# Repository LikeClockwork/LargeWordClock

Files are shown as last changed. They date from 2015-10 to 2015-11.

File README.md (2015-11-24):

# Like Clockwork Large Word Clock Design Files and Software

This repository holds the PCB/laser etch design files and Arduino code for my version of the word clock.

These PCBs and the laser cut glass faces are currently available via my store at: http://www.likeclockworkdesign.com/collections/kits/products/the-standard-makers-kit

The PCB measures 399x399mm and the glass faceplace measures 17"x17".

The PCBs are Arduino compatible and it runs the “Arduino on a breadboard” bootloader. The microcontroller is a Atmega328p (TQFP package) running at 8MHz that drives four 16x8 LED (512 LEDs) matrixes via four HT16K33’s. Time keeping is accomplished using a DS321 real time clock.  There is a linear power regulator on board to step down 9-12V input voltage to 5V. 

All unused Arduino pins are broken out to a pin header. Happy hacking!

The posted PCBs have been fabricated, assembled, and confirmed as working with the posted code.

*Upcoming Changes:*

The boards shipped ~~for the Kickstarter~~ going forward will have the following enhancements:
+ Addition of a footprint so that you can plug in standard Arduino shields. Done!

+ The ability to replace all ICs with prebuilt modules (Arduino Nano vs. Atmega328p, Adafruit matrix drivers vs. HT16K33s) for those who don’t want to drag solder tiny leads. Done!

+ Addition of a prototyping area to make use of all that extra real-estate. Done!

+ Addition of an Open Source Hardware logo. Done!

*Thanks to:*

+ The Kickstarter Backers
+ CERN for building KiCad and making it free.
+ Adafruit for their great libraries and making awesome breakout boards.

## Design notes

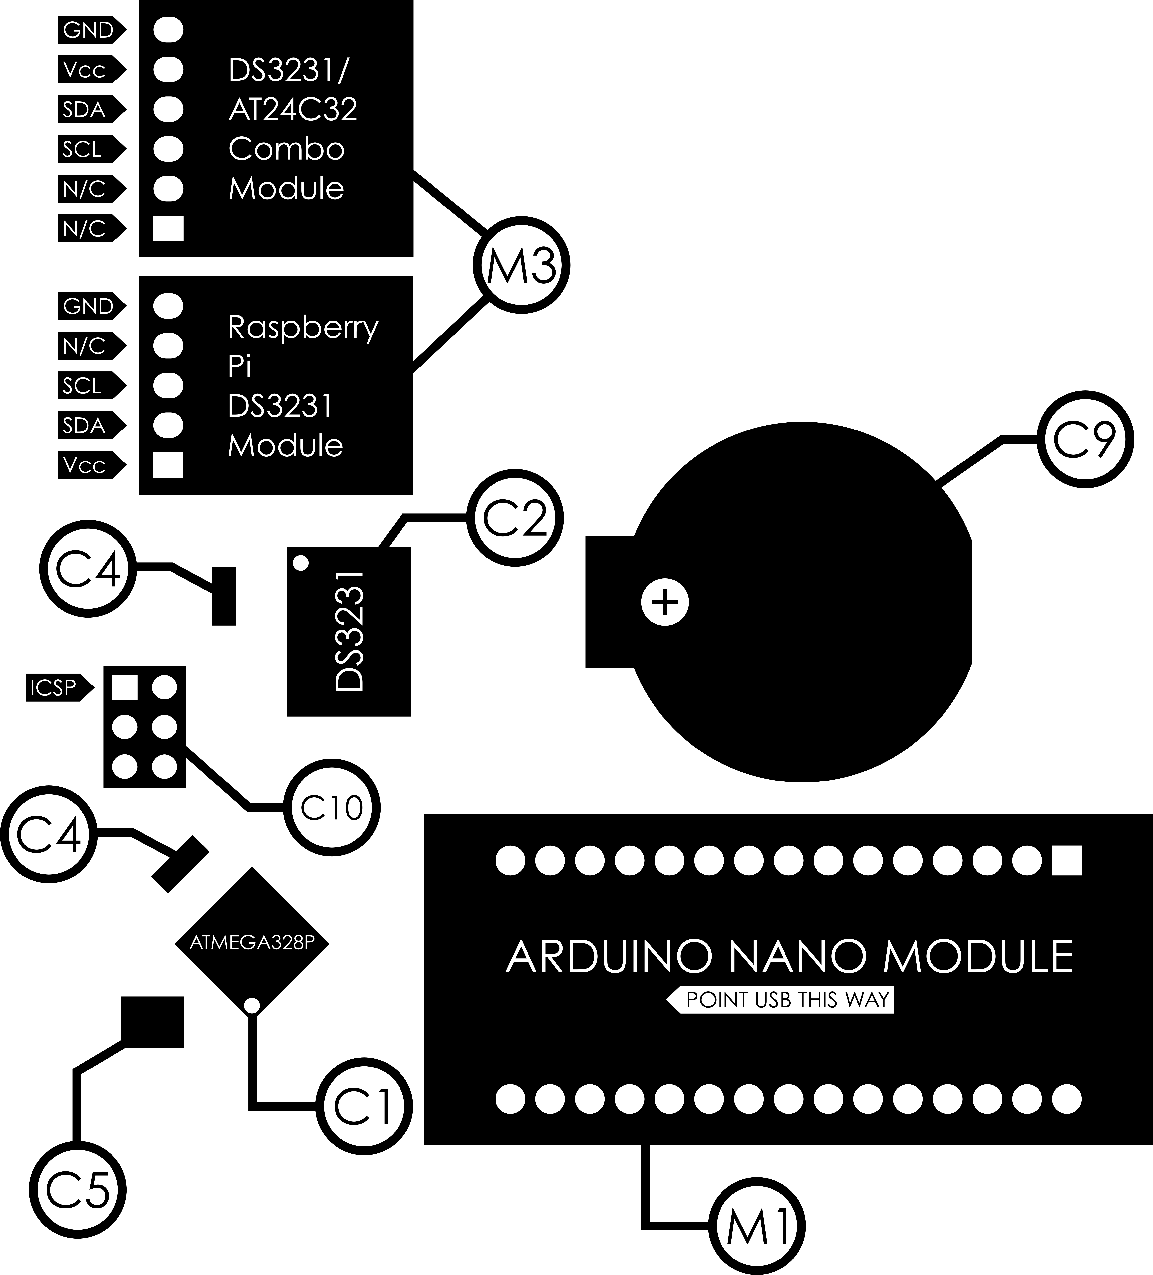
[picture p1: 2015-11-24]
KiCad/LargeKickstarter/SVG/nano_section.png

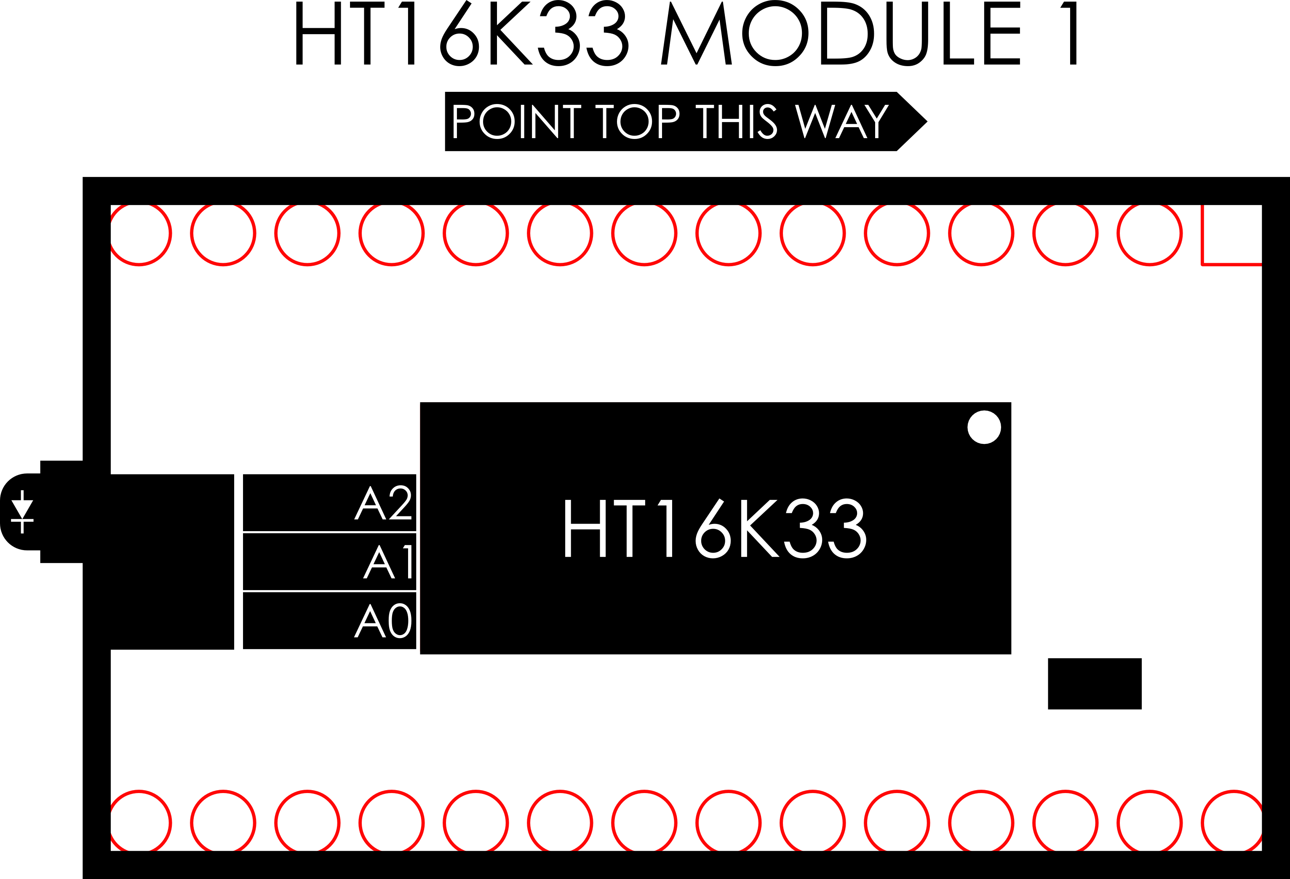
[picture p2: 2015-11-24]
KiCad/LargeKickstarter/SVG/HT-Module1.png

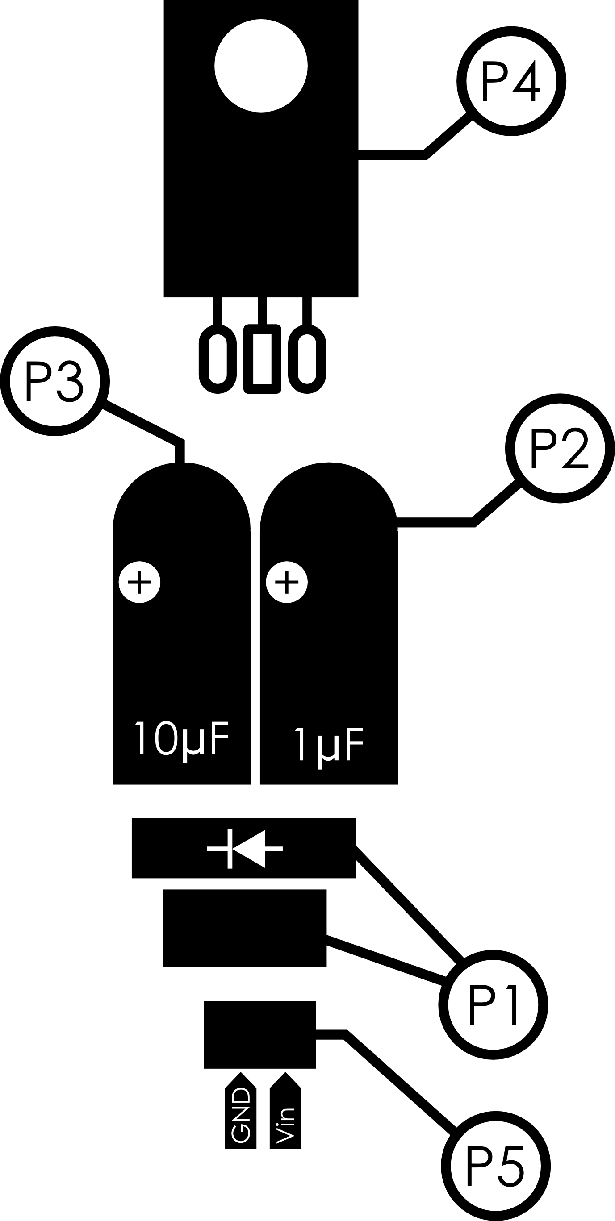
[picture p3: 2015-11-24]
KiCad/LargeKickstarter/SVG/power_section.png

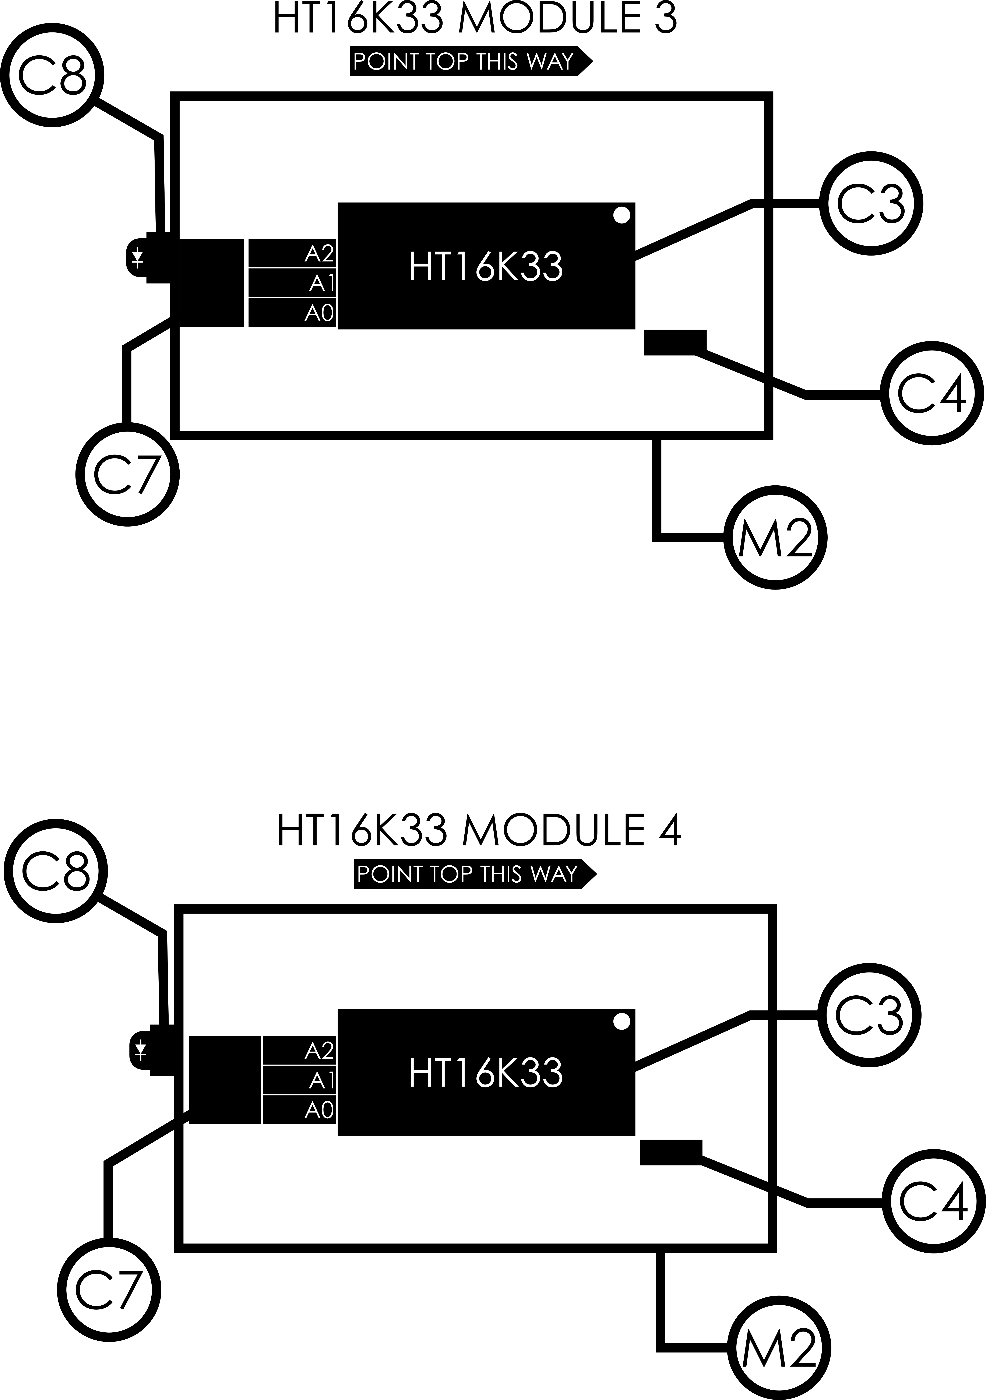
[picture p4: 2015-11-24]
KiCad/LargeKickstarter/SVG/bottom_matrix.png

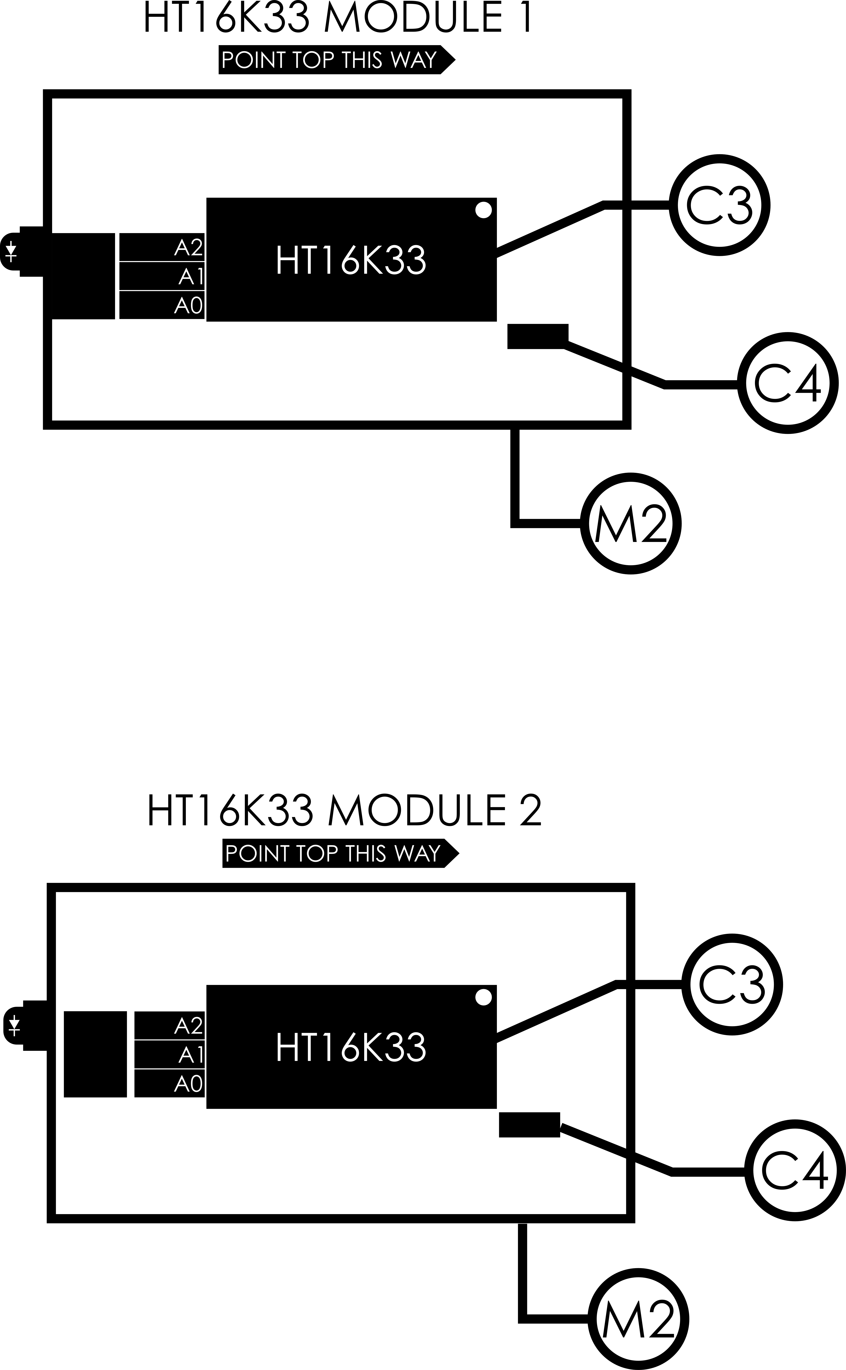
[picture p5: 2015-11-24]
KiCad/LargeKickstarter/SVG/top_matrix.png

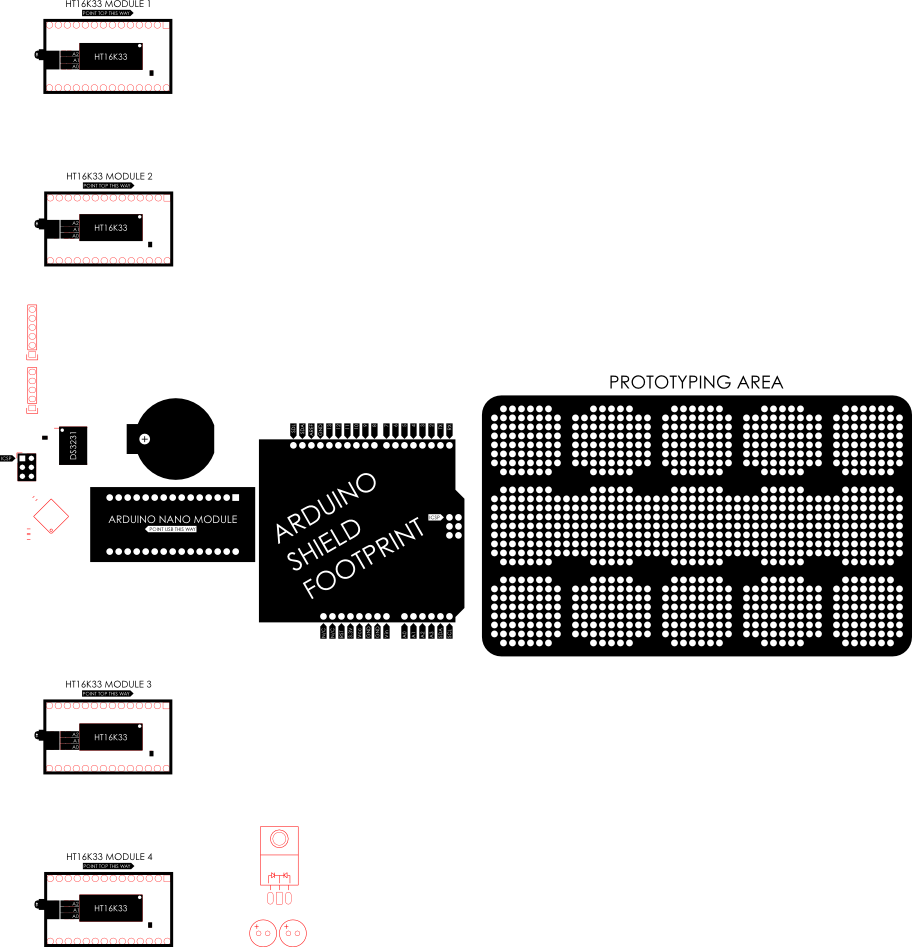
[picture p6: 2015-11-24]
KiCad/LargeKickstarter/SVG/g44480-2.png

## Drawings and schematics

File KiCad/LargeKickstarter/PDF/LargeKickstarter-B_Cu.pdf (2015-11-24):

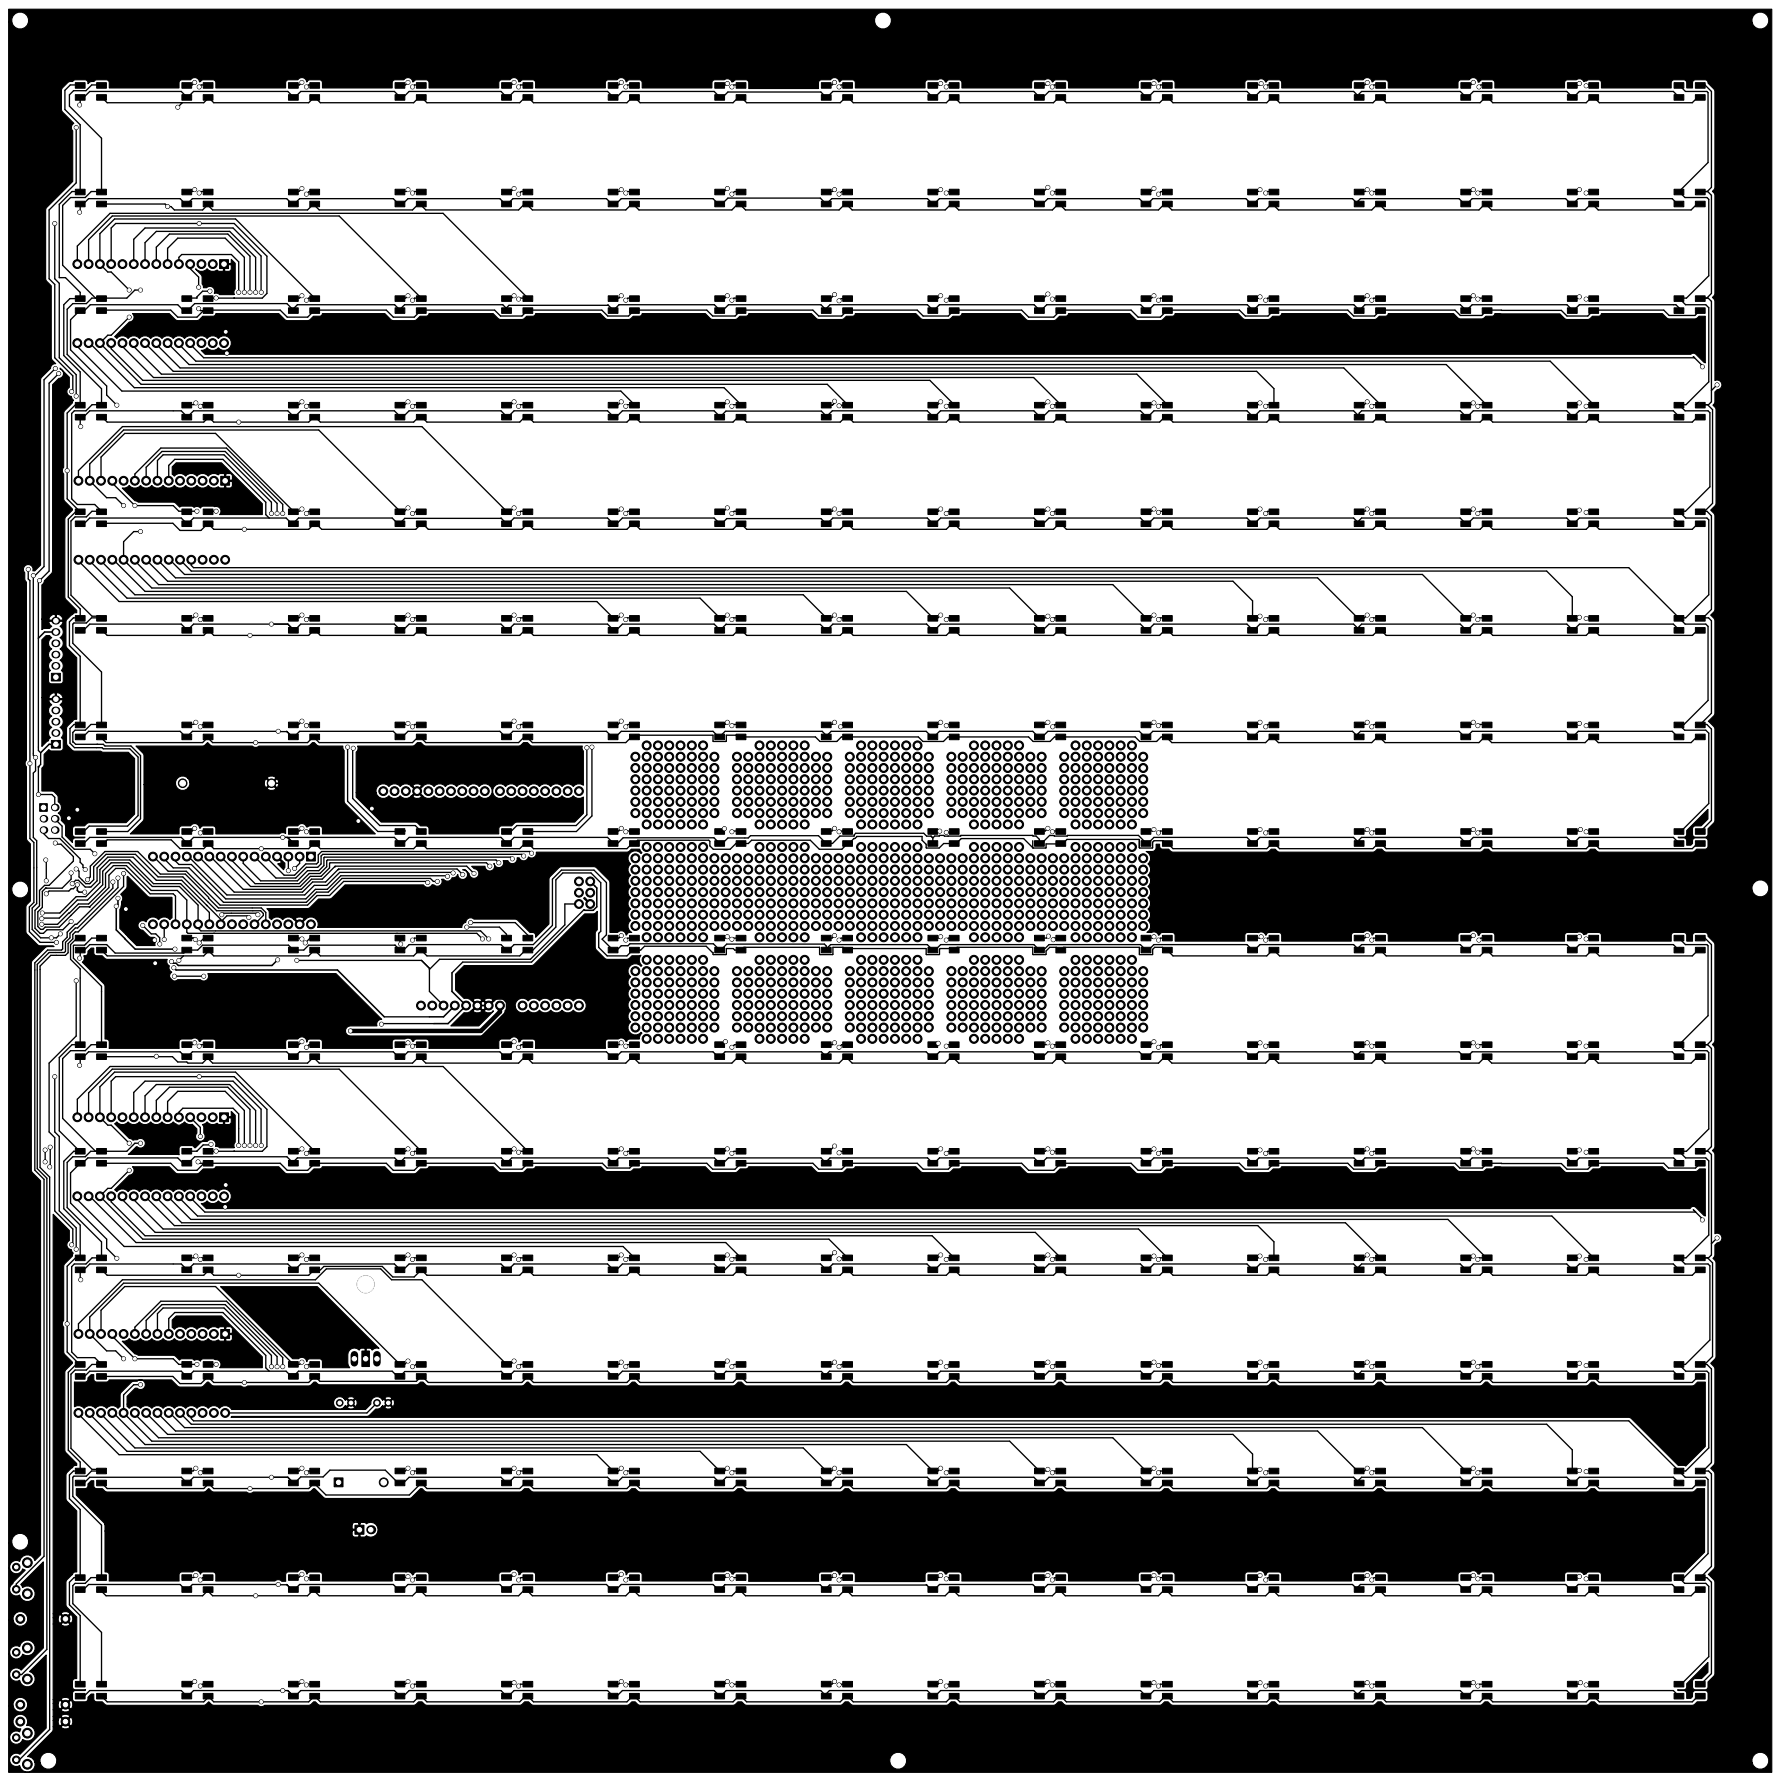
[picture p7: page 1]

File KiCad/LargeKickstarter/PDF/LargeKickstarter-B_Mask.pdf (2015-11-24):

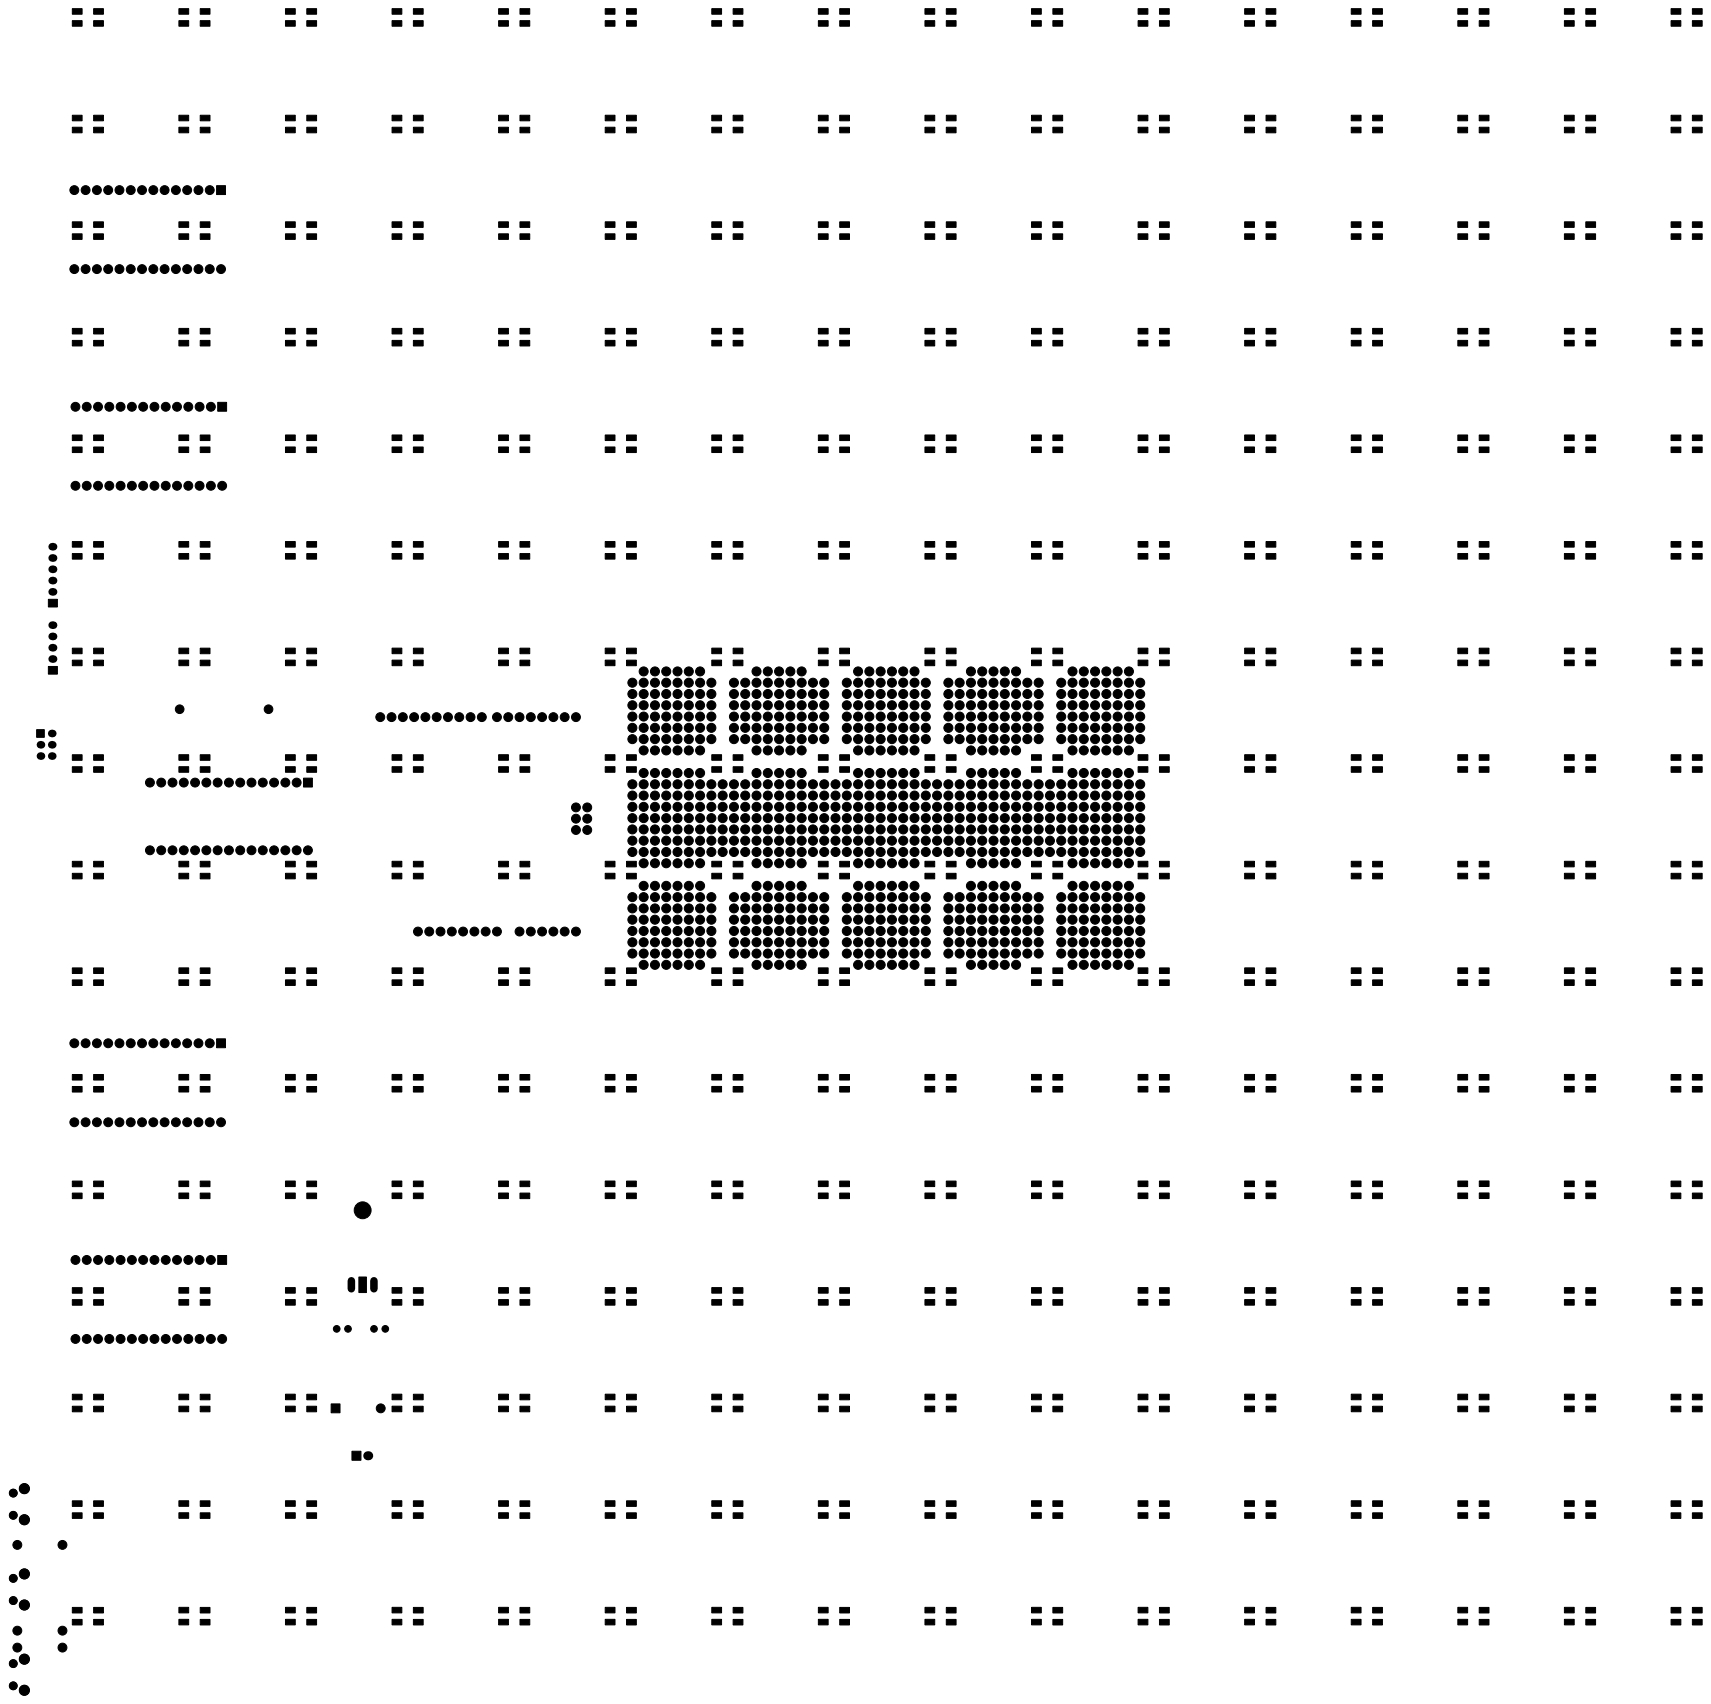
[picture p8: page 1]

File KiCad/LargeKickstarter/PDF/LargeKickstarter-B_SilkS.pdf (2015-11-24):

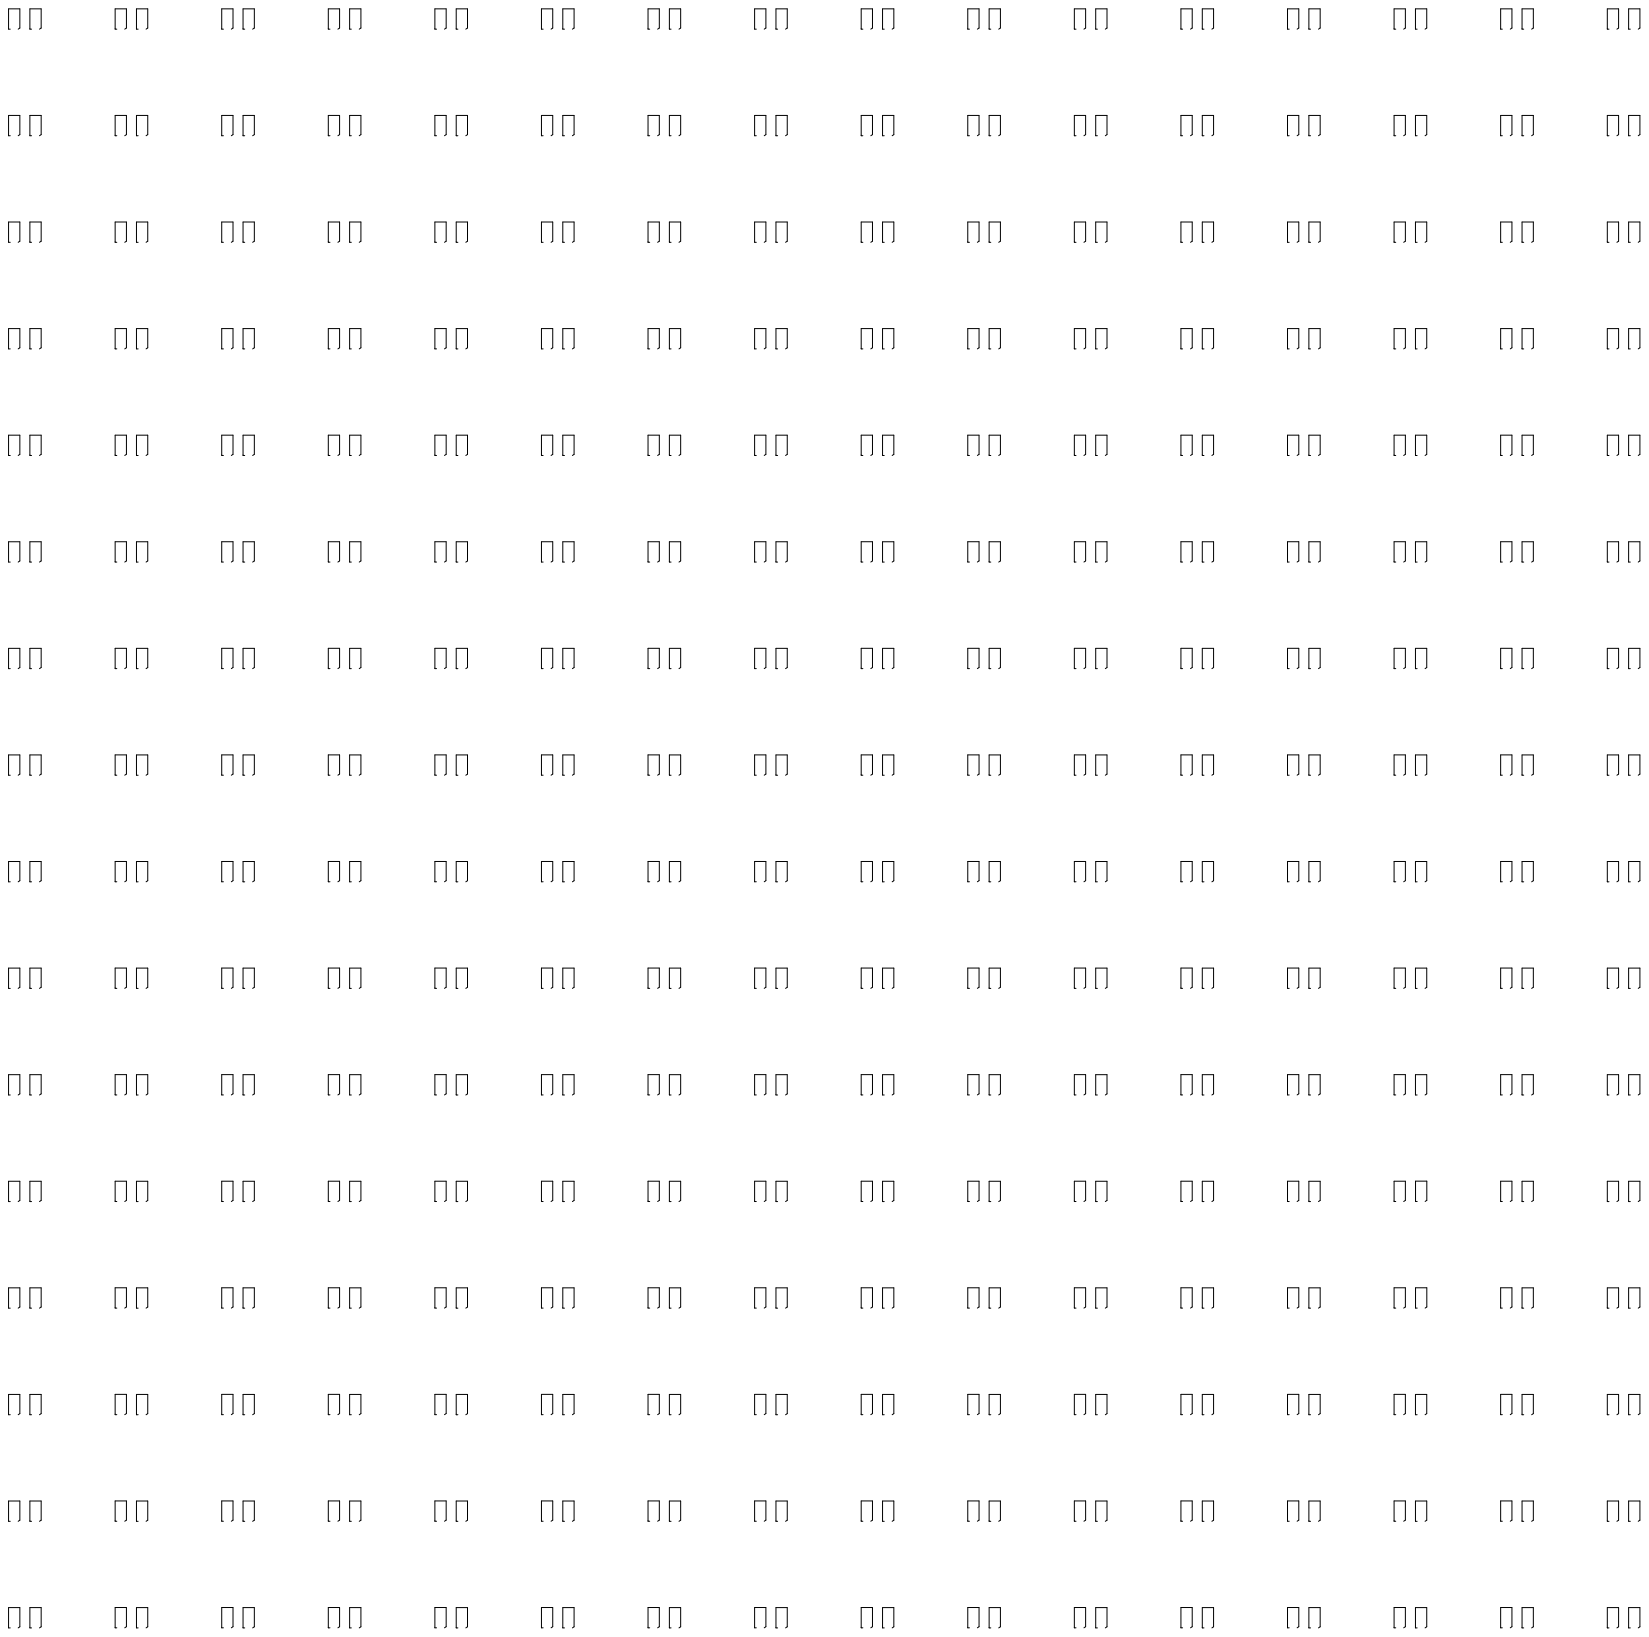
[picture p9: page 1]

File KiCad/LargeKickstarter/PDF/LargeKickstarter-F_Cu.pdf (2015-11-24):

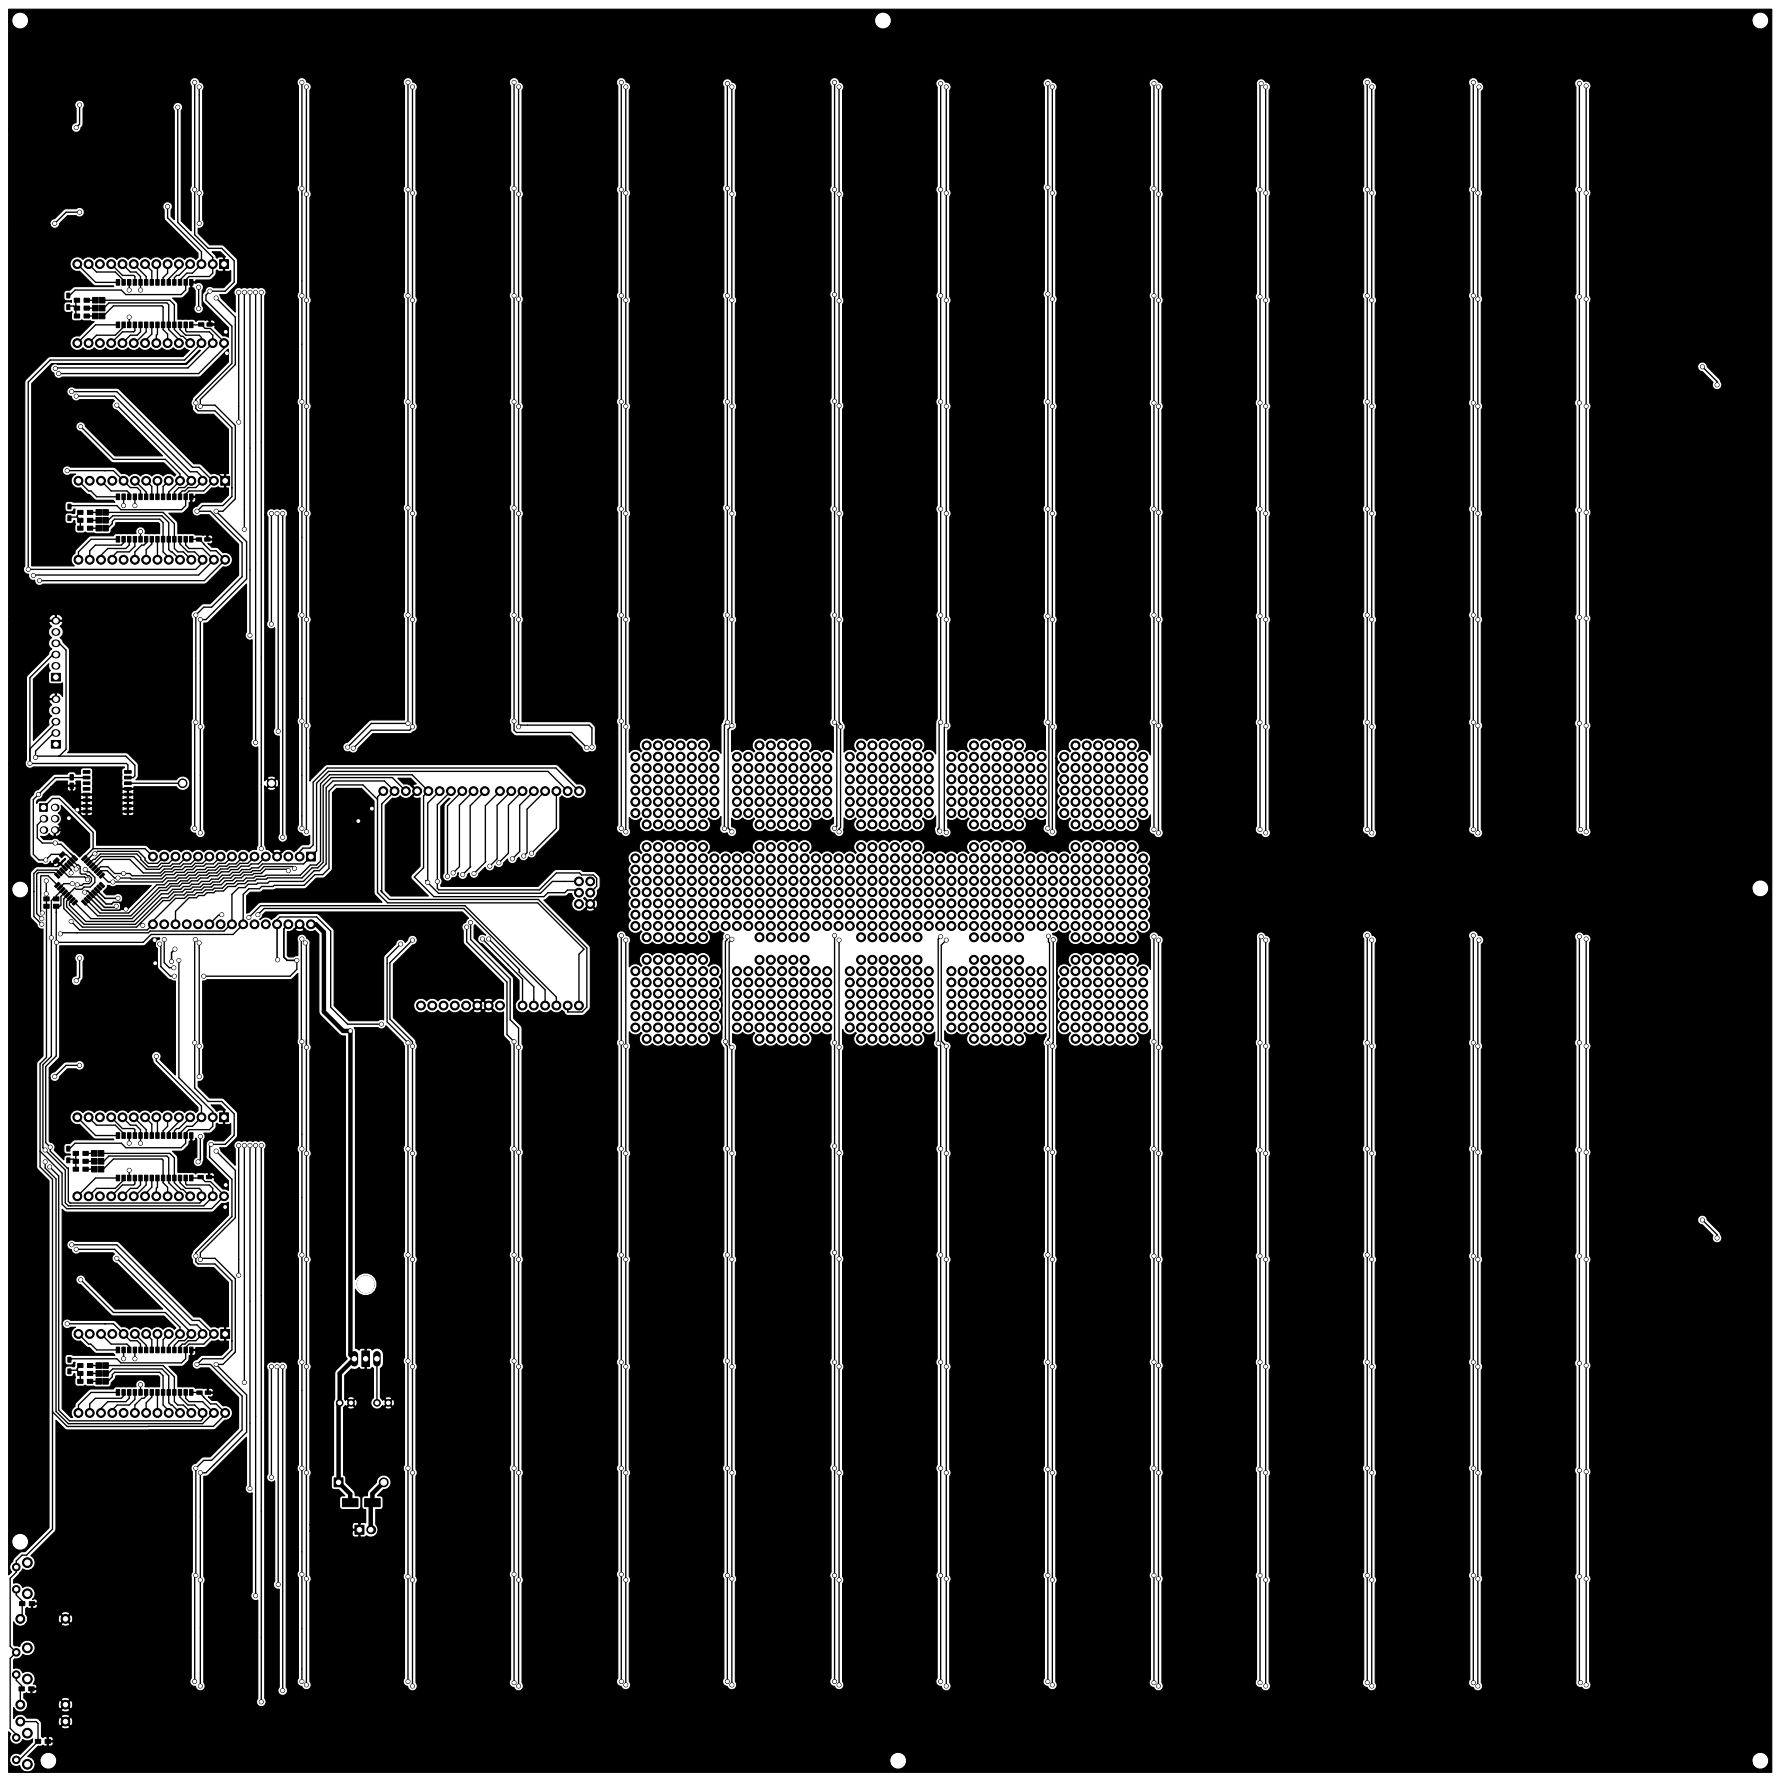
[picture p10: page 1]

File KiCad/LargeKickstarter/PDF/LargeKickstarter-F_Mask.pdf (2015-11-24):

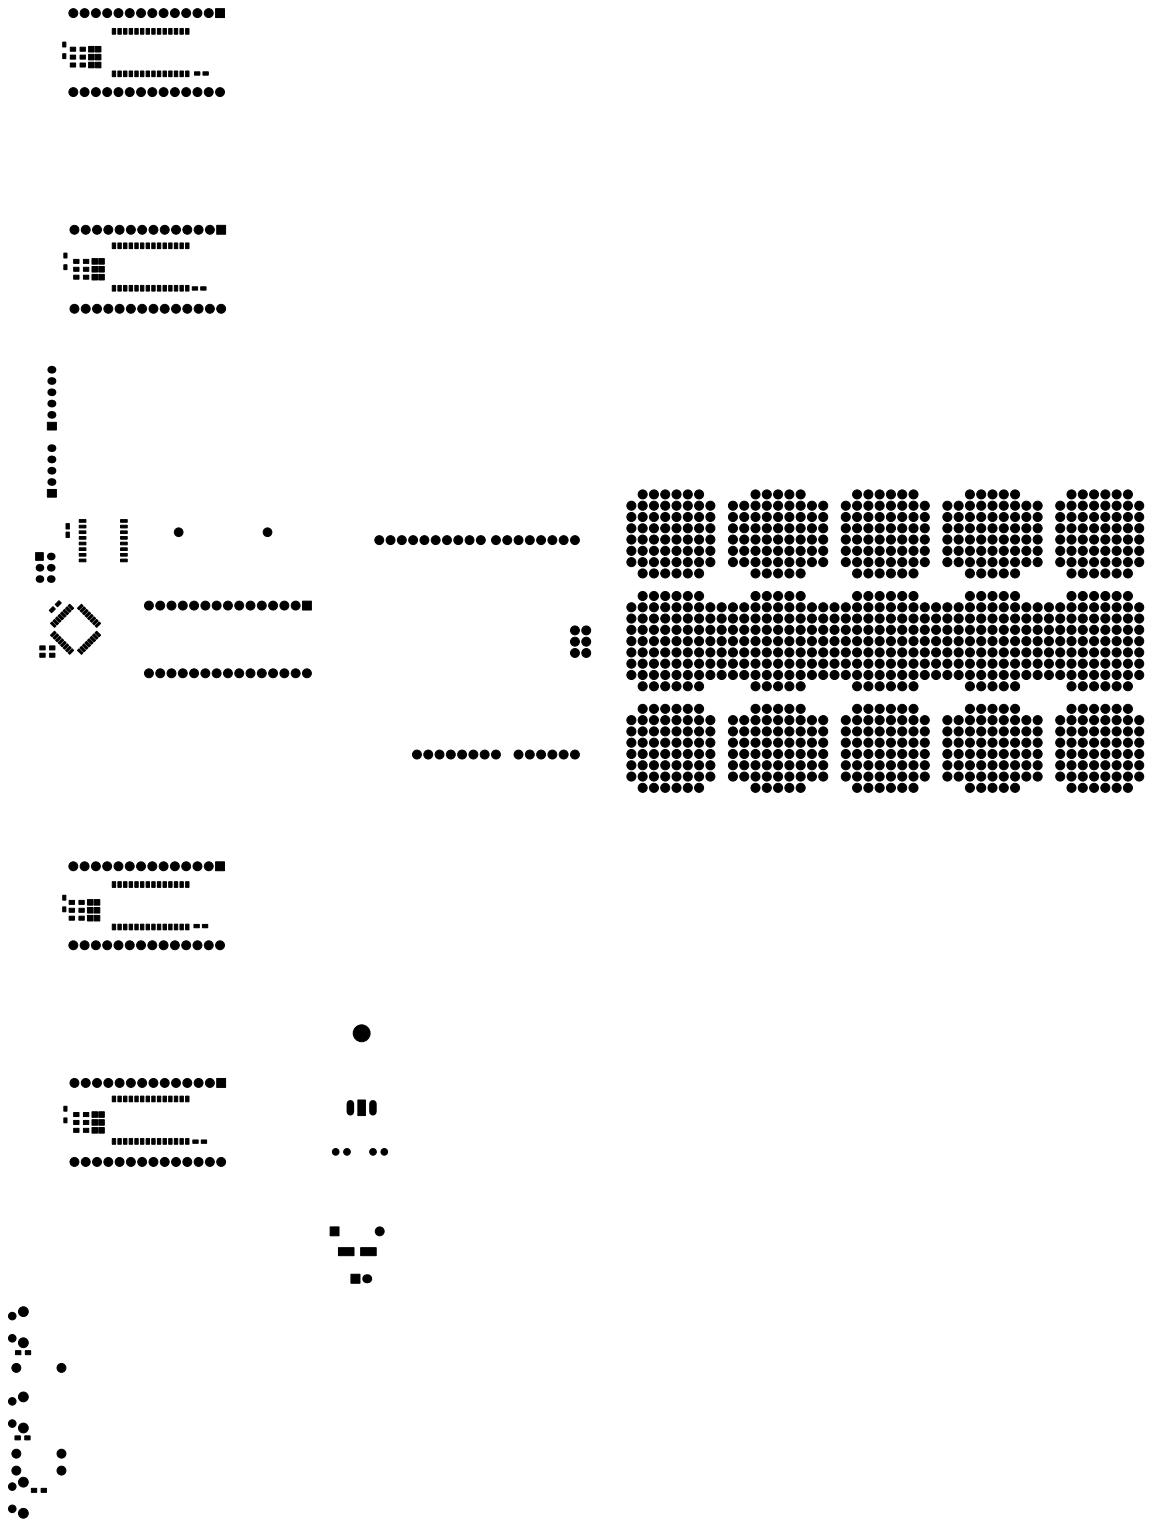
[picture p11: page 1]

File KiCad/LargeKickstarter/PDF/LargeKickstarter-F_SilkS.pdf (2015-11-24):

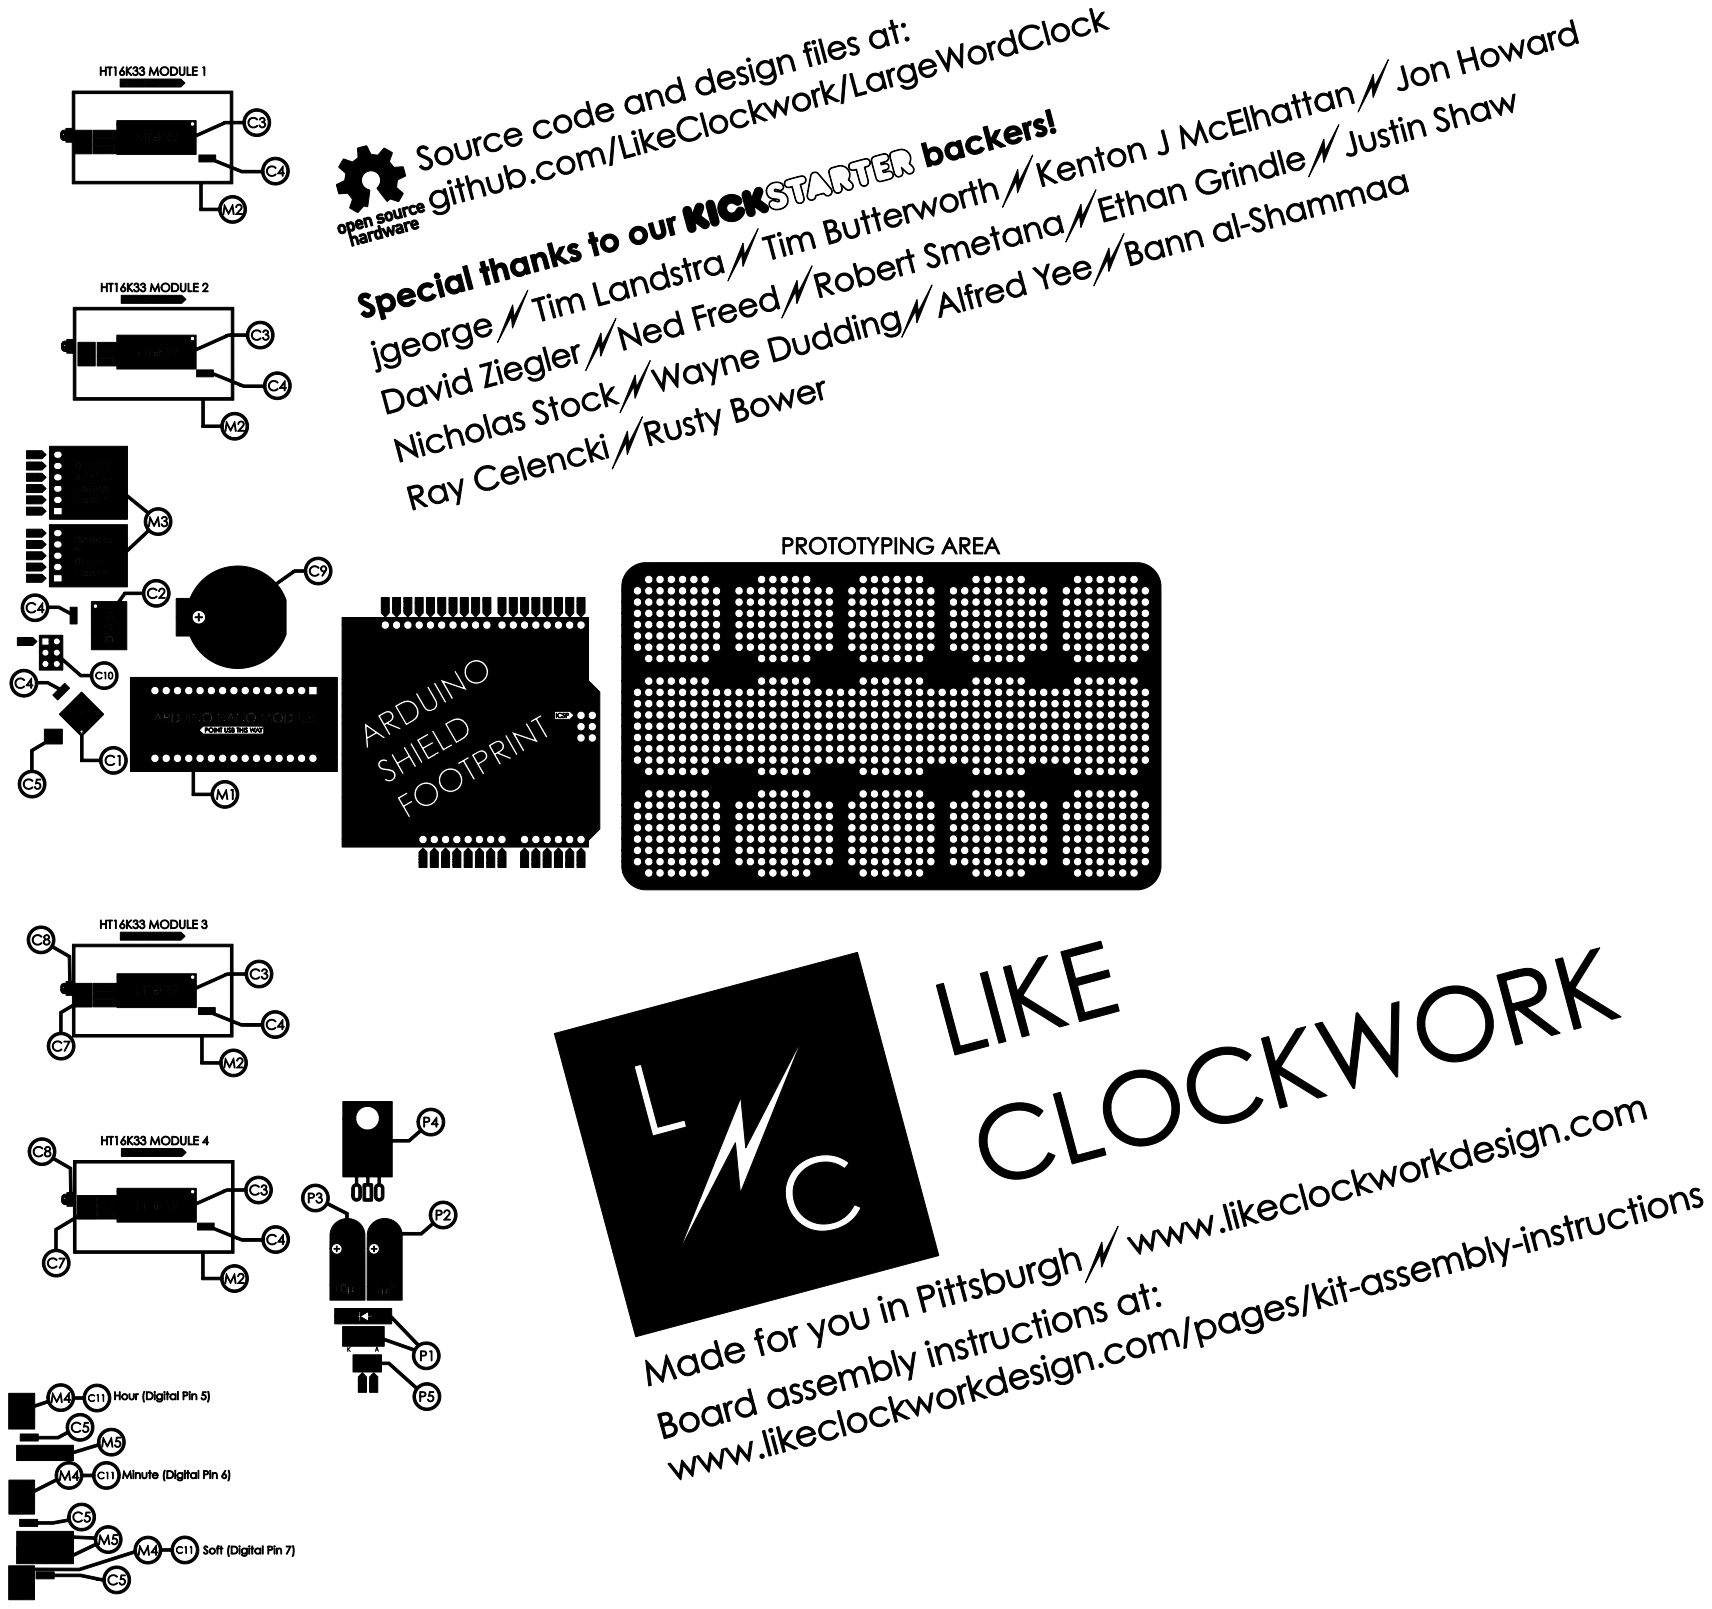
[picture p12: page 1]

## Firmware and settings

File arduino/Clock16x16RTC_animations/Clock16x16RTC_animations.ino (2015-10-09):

#include <Wire.h>
#include <RTClib.h>
#include "Adafruit_LEDBackpack.h"
#include "Adafruit_GFX.h"
#include "Clock16x16mapping.h"


RTC_DS1307 RTC;
Adafruit_8x16matrix matrix = Adafruit_8x16matrix();
Adafruit_8x16matrix matrix2 = Adafruit_8x16matrix();


uint16_t active[16];  //Holds active matrix
uint16_t last[16];  //Holds previous matrix

unsigned int curHours;
unsigned int hours = 99;
unsigned int curMins;
unsigned int mins = 99;
int aniChoice = 0;

void setup() { 
  //Serial.begin(57600);

  
  RTC.begin();
  delay(100);
 
matrix.begin(0x71);  // pass in the address
matrix2.begin(0x70);  // pass in the address
delay(100);
 
 matrix.clear();
 matrix2.clear();
 matrix.writeDisplay();
 matrix2.writeDisplay();
 matrix2.drawPixel(8, 15, LED_ON);
 matrix2.writeDisplay();  
 matrix2.drawPixel(8, 15, LED_OFF);
 matrix2.writeDisplay();  
 matrix2.drawPixel(8, 15, LED_ON);
 matrix2.writeDisplay();  
 matrix2.drawPixel(8, 15, LED_OFF);
 matrix2.writeDisplay(); 

 pinMode(5, INPUT);
 pinMode(6, INPUT);
 pinMode(7, INPUT);

  if(!RTC.isrunning()) {
    RTC.adjust(DateTime(2015,4,18,0,0,0));
  }

  DateTime now = RTC.now();

  hours = now.hour();
  mins = now.minute(); 
  doAnimation();  
  delay(100);

}

unsigned long currentMillis = millis();
unsigned long previousMillis = 0; 
unsigned long resetMillis = 0; 
unsigned long pressCheckA0 = 0;
unsigned long pressCheckA1 = 0;
unsigned long pressCheckA2 = 0;


bool A0pressed = false;
bool A1pressed = false;
bool A2pressed = false;
bool A0read = false;
bool A1read = false;
bool A2read = false;

void loop () {
  
 
   if((unsigned long)(currentMillis - previousMillis) >= 5000)  {
   
    //Serial.print(hours);
    //Serial.print(':');
    //Serial.println(mins);
    checkTime();
    previousMillis = currentMillis; 
     
  }
   
  
  if( digitalRead(5) == HIGH && A0pressed == false) {
     A0pressed = true;
     pressCheckA0 = currentMillis;
     A0read = false;
  }  

  if( digitalRead(6) == HIGH && A1pressed == false) {
      A1pressed = true;
      pressCheckA1 = currentMillis;
      A1read = false;
  }  


  if( digitalRead(7) == HIGH && A2pressed == false) {
      A2pressed = true;
      pressCheckA2 = currentMillis;
      A2read = false;
  }

  if( A0pressed == true && A0read == false && (unsigned long)(currentMillis - pressCheckA0) >= 50) {
      DateTime now = RTC.now();
      int newHour = now.hour() + 1;
      if (newHour > 23) {
         newHour = 0; 
      }
      RTC.adjust(DateTime(now.year(),now.month(),now.day(),newHour,now.minute(),now.second()));
      hours = newHour;
      mins = now.minute(); 
      curHours = newHour;
      curMins = now.minute(); 
      wipe();
      assemble();
      drawDisplay();
      A0read = true;
  }
  
  if( A1pressed == true && A1read == false && (unsigned long)(currentMillis - pressCheckA1) >= 50) {
      DateTime now = RTC.now();   
      int newMinute = now.minute() + 1;
      if (newMinute > 59) {
         newMinute = 0; 
      }
      RTC.adjust(DateTime(now.year(),now.month(),now.day(),now.hour(),newMinute,now.second()));
      hours = now.hour();
      mins = newMinute; 
      curHours = now.hour();
      curMins = newMinute;
      wipe();
      assemble();
      drawDisplay();
      A1read = true;
  }


  if( A2pressed == true && A2read == false && (unsigned long)(currentMillis - pressCheckA2) >= 50) {  
      aniChoice++;
      sampleAnimation();
      A2read = true;
  }


  if( digitalRead(5) == LOW) {
     A0pressed = false; 
     A0read = false;
  }
   
  if( digitalRead(6) == LOW) {
     A1pressed = false; 
     A1read = false;
  } 
 
  if( digitalRead(7) == LOW) {
     A2pressed = false; 
     A2read = false;
  } 

  wipe();
  assemble();
  delay(10); 
  currentMillis = millis();
}

void checkTime () {
  DateTime now = RTC.now();
  curHours = now.hour();
  curMins = now.minute();  

  if (curHours != hours || curMins != mins) {
    hours = curHours;
    mins = curMins;
   //software_Reset();
    doAnimation();

  }  
  
}



void assemble() {
  
  for( int i = 0; i < 16; i++ ) {
    active[i] = active[i] | pgm_read_word(&(it_is[i]));
  }  
  
  
  //flag midnight   
  if (hours == 0 && mins == 0 ) {
    for( int i = 0; i < 16; i++ ) {
      active[i] = active[i] | pgm_read_word(&(midnight[i]));
    }     
  }
  
  //flag noon   
  if ( hours == 12 && mins == 0) {
    for( int i = 0; i < 16; i++ ) {
      active[i] = active[i] | pgm_read_word(&(noon[i]));
    }     
  }
  
  //If it's between 12:01 and 5:59 in the PM, flag in the afternoon   
  if (hours > 12 && hours < 18 || ( hours == 12 && mins > 0 )) {
      for( int i = 0; i < 16; i++ ) {
        active[i] = active[i] | pgm_read_word(&(in_the_afternoon[i]));
      }
  }  
  
  //If it's between 6 and 8:59 in the PM, flag in the evening   
  if (hours > 17 && hours < 21) {
    for( int i = 0; i < 16; i++ ) {
      active[i] = active[i] | pgm_read_word(&(in_the_evening[i]));
    }     
  }
  
  
  //If it's between 9 and midnight in the PM, flag at night   
  if (hours > 20 ) {
    for( int i = 0; i < 16; i++ ) {
      active[i] = active[i] | pgm_read_word(&(at_night[i]));
    }     
  }
  
  //If it's between 12:01 and 11:59 in the AM, flag in the morning  
  if ((hours > 0 && hours < 12) || (hours == 0 && mins > 0) ) {
      for( int i = 0; i < 16; i++ ) {
        active[i] = active[i] | pgm_read_word(&(in_the_morning[i]));
      }   
  }

  if ( mins == 0  && (hours != 12 && hours != 0)) {
    for( int i = 0; i < 16; i++ ) {
      active[i] = active[i] | pgm_read_word(&(o_clock[i]));
    }
  }  
  
  if ( mins < 10 && mins > 0) {
    for( int i = 0; i < 16; i++ ) {
      active[i] = active[i] | pgm_read_word(&(o[i]));
    }
  }  
  
  if ( hours == 12 && mins != 0) {
    for( int i = 0; i < 16; i++ ) {
      active[i] = active[i] | pgm_read_word(&(h12[i]));
    }
  }  
  
  if ( hours == 0 && mins != 0) {
    for( int i = 0; i < 16; i++ ) {
      active[i] = active[i] | pgm_read_word(&(h12[i]));
    }
  }  
  
  if ( hours == 1 || hours == 13) {
    for( int i = 0; i < 16; i++ ) {
      active[i] = active[i] | pgm_read_word(&(h1[i]));
    }
  }
  
  if ( hours == 2 || hours == 14) {
    for( int i = 0; i < 16; i++ ) {
      active[i] = active[i] | pgm_read_word(&(h2[i]));
    }
  }
  
  if ( hours == 3 || hours == 15) {
    for( int i = 0; i < 16; i++ ) {
      active[i] = active[i] | pgm_read_word(&(h3[i]));
    }
  } 
  
  if ( hours == 4 || hours == 16) {
    for( int i = 0; i < 16; i++ ) {
      active[i] = active[i] | pgm_read_word(&(h4[i]));
    }
  } 
  
  if ( hours == 1) {
    for( int i = 0; i < 16; i++ ) {
      active[i] = active[i] | pgm_read_word(&(h1[i]));
    }
  } 
  
  if ( hours == 5 || hours == 17) {
    for( int i = 0; i < 16; i++ ) {
      active[i] = active[i] | pgm_read_word(&(h5[i]));
    }
  } 
  
  if ( hours == 6 || hours == 18) {
    for( int i = 0; i < 16; i++ ) {
      active[i] = active[i] | pgm_read_word(&(h6[i]));
    }
  } 
  
  if ( hours == 7 || hours == 19) {
    for( int i = 0; i < 16; i++ ) {
      active[i] = active[i] | pgm_read_word(&(h7[i]));
    }
  } 
  
  if ( hours == 8 || hours == 20) {
    for( int i = 0; i < 16; i++ ) {
      active[i] = active[i] | pgm_read_word(&(h8[i]));
    }
  } 
  
  if ( hours == 9 || hours == 21) {
    for( int i = 0; i < 16; i++ ) {
      active[i] = active[i] | pgm_read_word(&(h9[i]));
    }
  } 
  
  if ( hours == 10 || hours == 22) {
    for( int i = 0; i < 16; i++ ) {
      active[i] = active[i] | pgm_read_word(&(h10[i]));
    }
  }
  
  if ( hours == 11 || hours == 23) {
    for( int i = 0; i < 16; i++ ) {
      active[i] = active[i] | pgm_read_word(&(h11[i]));
    }
  } 

  
  if ( mins == 1 || mins == 21 || mins == 31 || mins == 41 || mins == 51) {
    for( int i = 0; i < 16; i++ ) {
      active[i] = active[i] | pgm_read_word(&(m1[i]));
    }
  } 
  
  if ( mins == 2 || mins == 22 || mins == 32 || mins == 42 || mins == 52) {
    for( int i = 0; i < 16; i++ ) {
      active[i] = active[i] | pgm_read_word(&(m2[i]));
    }
  }
  
  if ( mins == 3 || mins == 23 || mins == 33 || mins == 43 || mins == 53) {
    for( int i = 0; i < 16; i++ ) {
      active[i] = active[i] | pgm_read_word(&(m3[i]));
    }
  }
  
  if ( mins == 4 || mins == 24 || mins == 34 || mins == 44 || mins == 54) {
    for( int i = 0; i < 16; i++ ) {
      active[i] = active[i] | pgm_read_word(&(m4[i]));
    }
  }
  
  if ( mins == 5 || mins == 25 || mins == 35 || mins == 45 || mins == 55) {
    for( int i = 0; i < 16; i++ ) {
      active[i] = active[i] | pgm_read_word(&(m5[i]));
    }
  }
  
  if ( mins == 6 || mins == 26 || mins == 36 || mins == 46 || mins == 56) {
    for( int i = 0; i < 16; i++ ) {
      active[i] = active[i] | pgm_read_word(&(m6[i]));
    }
  }
  
  if ( mins == 7 || mins == 27 || mins == 37 || mins == 47 || mins == 57) {
    for( int i = 0; i < 16; i++ ) {
      active[i] = active[i] | pgm_read_word(&(m7[i]));
    }
  }
  
  if ( mins == 8 || mins == 28 || mins == 38 || mins == 48 || mins == 58) {
    for( int i = 0; i < 16; i++ ) {
      active[i] = active[i] | pgm_read_word(&(m8[i]));
    }
  }
  
  if ( mins == 9 || mins == 29 || mins == 39 || mins == 49 || mins == 59) {
    for( int i = 0; i < 16; i++ ) {
      active[i] = active[i] | pgm_read_word(&(m9[i]));
    }
  }
  
  if ( mins == 10 ) {
    for( int i = 0; i < 16; i++ ) {
      active[i] = active[i] | pgm_read_word(&(m10[i]));
    }
  }  
  
  if ( mins == 11 ) {
    for( int i = 0; i < 16; i++ ) {
      active[i] = active[i] | pgm_read_word(&(m11[i]));
    }
  }  
  
  if ( mins == 12 ) {
    for( int i = 0; i < 16; i++ ) {
      active[i] = active[i] | pgm_read_word(&(m12[i]));
    }
  }  
  
  if ( mins == 13 ) {
    for( int i = 0; i < 16; i++ ) {
      active[i] = active[i] | pgm_read_word(&(m13[i]));
    }
  }  
  
  if ( mins == 14 ) {
    for( int i = 0; i < 16; i++ ) {
      active[i] = active[i] | pgm_read_word(&(m14[i]));
    }
  }  
  
  if ( mins == 15 ) {
    for( int i = 0; i < 16; i++ ) {
      active[i] = active[i] | pgm_read_word(&(m15[i]));
    }
  }  
  
  if ( mins == 16 ) {
    for( int i = 0; i < 16; i++ ) {
      active[i] = active[i] | pgm_read_word(&(m16[i]));
    }
  }  
  
  if ( mins == 17 ) {
    for( int i = 0; i < 16; i++ ) {
      active[i] = active[i] | pgm_read_word(&(m17[i]));
    }
  }  
  
  if ( mins == 18 ) {
    for( int i = 0; i < 16; i++ ) {
      active[i] = active[i] | pgm_read_word(&(m18[i]));
    }
  }  
  
  if ( mins == 19 ) {
    for( int i = 0; i < 16; i++ ) {
      active[i] = active[i] | pgm_read_word(&(m19[i]));
    }
  }   
  
  if ( mins >= 20 && mins < 30 ) {
    for( int i = 0; i < 16; i++ ) {
      active[i] = active[i] | pgm_read_word(&(m20[i]));
    }
  }   
  
  if ( mins >= 30 && mins < 40 ) {
    for( int i = 0; i < 16; i++ ) {
      active[i] = active[i] | pgm_read_word(&(m30[i]));
    }
  }  
  
  if ( mins >= 40 && mins < 50 ) {
    for( int i = 0; i < 16; i++ ) {
      active[i] = active[i] | pgm_read_word(&(m40[i]));
    }
  }    
  
  if ( mins >= 50 && mins < 60 ) {
    for( int i = 0; i < 16; i++ ) {
      active[i] = active[i] | pgm_read_word(&(m50[i]));
    }
  } 

}

void wipe () {
    for( int i = 0; i < 16; i++ ) {
      active[i] = 0b0000000000000000;
    }  
}


//Animation functions

//No animation
void drawDisplay() {      
    
    matrix.clear();
    matrix2.clear();
    wipe();
    assemble();
    
     for( int y = 16; y >= 0; y-- ) {
       for( int x = 0; x < 16; x++) {  

         if(bitRead( active[15 - y] , 15 - x)) {
            if( y < 8) {
                matrix.drawPixel(y, x, LED_ON);  
            } else {
                matrix2.drawPixel(y - 8, x, LED_ON);                
            }
          } else {

          }
        } 
     }
      matrix.writeDisplay();  
      matrix2.writeDisplay(); 
}

//Fade out and back in
void fadeOut() {
     for(int b = 16; b >= 0; b--) {
       matrix.setBrightness(b); 
       matrix2.setBrightness(b); 
       delay(50);
    }
    wipe();
    assemble();
    drawDisplay();

    delay(100);

    for(int b = 0; b < 16 ; b++) {
       matrix.setBrightness(b); 
       matrix2.setBrightness(b); 
       delay(50);
    } 
}

//Random dissolve to all on, then fade back to time
void whiteOut () {
  
      int randomizer[256] = {
        1, 2, 3, 4, 5, 6, 7, 8, 9, 10, 11, 12, 13, 14, 15, 16,
        17, 18, 19, 20, 21, 22, 23, 24, 25, 26, 27, 28, 29, 30, 31, 32,
        33, 34, 35, 36, 37, 38, 39, 40, 41, 42, 43, 44, 45, 46, 47, 48,
        49, 50, 51, 52, 53, 54, 55, 56, 57, 58, 59, 60, 61, 62, 63, 64,
        65, 66, 67, 68, 69, 70, 71, 72, 73, 74, 75, 76, 77, 78, 79, 80,
        81, 82, 83, 84, 85, 86, 87, 88, 89, 90, 91, 92, 93, 94, 95, 96,
        97, 98, 99, 100, 101, 102, 103, 104, 105, 106, 107, 108, 109, 110, 111, 112,
        113, 114, 115, 116, 117, 118, 119, 120, 121, 122, 123, 124, 125, 126, 127, 128,
        129, 130, 131, 132, 133, 134, 135, 136, 137, 138, 139, 140, 141, 142, 143, 144,
        145, 146, 147, 148, 149, 150, 151, 152, 153, 154, 155, 156, 157, 158, 159, 160, 
        161, 162, 163, 164, 165, 166, 167, 168, 169, 170, 171, 172, 173, 174, 175, 176, 
        177, 178, 179, 180, 181, 182, 183, 184, 185, 186, 187, 188, 189, 190, 191, 192, 
        193, 194, 195, 196, 197, 198, 199, 200, 201, 202, 203, 204, 205, 206, 207, 208, 
        209, 210, 211, 212, 213, 214, 215, 216, 217, 218, 219, 220, 221, 222, 223, 224, 
        225, 226, 227, 228, 229, 230, 231, 232, 233, 234, 235, 236, 237, 238, 239, 240, 
        241, 242, 243, 244, 245, 246, 247, 248, 249, 250, 251, 252, 253, 254, 255, 256
      };  
  

     bubbleUnsort (randomizer, 256);    
  
     for( int i = 0; i < 256; i++) {
        
          int y = randomizer[i ]/16;
          int x = randomizer[i ]%16;
   
         if( y < 8) {
            matrix.drawPixel(y, x, LED_ON);  
          } else {
            matrix2.drawPixel(y - 8, x, LED_ON);                
          }

     
        matrix.writeDisplay();  
        matrix2.writeDisplay();
        
     }
     
     wipe();
     bubbleUnsort (randomizer, 256);    
     assemble();

     for( int i = 0; i < 256; i++) {
        
          int y = randomizer[i]/16;
          int x = randomizer[i]%16;
   
         if(bitRead( active[15 - y] , 15 - x)) {
            if( y < 8) {
                matrix.drawPixel(y, x, LED_ON);  
            } else {
                matrix2.drawPixel(y - 8, x, LED_ON);                
            }
          } else {
            if( y < 8) {
                matrix.drawPixel(y, x, LED_OFF);  
            } else {
                matrix2.drawPixel(y - 8, x, LED_OFF);                
            }            
          }
       
     
        matrix.writeDisplay();  
        matrix2.writeDisplay();
        
     }
}

//Horizontal sweep.
void sweep() {      
      
    for( int x = 0; x < 16; x++) {
      last[x] = active[x]; 
    }
    

     wipe();
     assemble();   
   
     for( int x = 0; x < 16; x++) {  
       
       for( int y = 16; y >= 0; y-- ) {   

         if(!bitRead( active[15 - y] , 15 - x)) {
            if( y < 8) {
                matrix.drawPixel(y, x, LED_OFF);  
            } else {
                matrix2.drawPixel(y - 8, x, LED_OFF);                
            }
          }
          matrix.writeDisplay();  
          matrix2.writeDisplay(); 
       }          
     }
     
     for( int x = 0; x < 16; x++) {  
       
       for( int y = 16; y >= 0; y-- ) {  
         
         if(bitRead( active[15 - y] , 15 - x)) {
            if( y < 8) {
                matrix.drawPixel(y, x, LED_ON);  
            } else {
                matrix2.drawPixel(y - 8, x, LED_ON);                
            }
          }
          
          matrix.writeDisplay();  
          matrix2.writeDisplay(); 
        } 
     }
}

//Matrixy.
void matrixy() {      
    wipe();
    assemble();
 
     int cols[16] = {0,1,2,3,4,5,6,7,8,9,10,11,12,13,14,15};
     bubbleUnsort( cols, 16);
 
     
     for(int r = 0; r < 2; r++) {
     
     for( int i = 0; i < 16; i++) {
     
     int x = cols[i];
     int x2 = cols[i+1];
     int x3 = cols[i+2];
     int x4 = cols[i+3];
 
     for( int y = 16; y >= 0; y-- ) {
                 
            if( y < 8) {
                matrix.drawPixel(y, x, LED_ON);
                matrix.drawPixel(y, x2, LED_ON);  
                matrix.drawPixel(y, x3, LED_ON);  
                matrix.drawPixel(y, x4, LED_ON);  
            } else {
                matrix2.drawPixel(y - 8, x, LED_ON);                
                matrix2.drawPixel(y - 8, x2, LED_ON);                
                matrix2.drawPixel(y - 8, x3, LED_ON);                
                matrix2.drawPixel(y - 8, x4, LED_ON);                


            }
           matrix.writeDisplay();  
          matrix2.writeDisplay();
         delay(10);
         
         if(!bitRead( active[15 - y] , 15 - x)) {
            if( y < 8) {
                matrix.drawPixel(y, x, LED_OFF);  
            } else {
                matrix2.drawPixel(y - 8, x, LED_OFF);                
            }
          }
         
         if(!bitRead( active[15 - y] , 15 - x2)) {
            if( y < 8) {
                matrix.drawPixel(y, x2, LED_OFF);  
            } else {
                matrix2.drawPixel(y - 8, x2, LED_OFF);                
            }
          }         
         if(!bitRead( active[15 - y] , 15 - x3)) {
            if( y < 8) {
                matrix.drawPixel(y, x3, LED_OFF);  
            } else {
                matrix2.drawPixel(y - 8, x3, LED_OFF);                
            }
          }         
         if(!bitRead( active[15 - y] , 15 - x4)) {
            if( y < 8) {
                matrix.drawPixel(y, x4, LED_OFF);  
            } else {
                matrix2.drawPixel(y - 8, x4, LED_OFF);                
            }
          }
         
          
          matrix.writeDisplay();  
          matrix2.writeDisplay();  
        } 
       
   }
     }

}

void sampleAnimation () {
  
  if( aniChoice > 5) {
     aniChoice = 0; 
  }
  
  
  if (aniChoice == 0 ) {
    matrix.clear();
    matrix2.clear();
    matrix.writeDisplay();  
    matrix2.writeDisplay();         
    delay(250);
    drawDisplay();
    delay(250);
    matrix.clear();
    matrix2.clear();
    matrix.writeDisplay();  
    matrix2.writeDisplay();         
    delay(250);
    drawDisplay();     
  }
  
  if (aniChoice == 1 ) {
    fadeOut();
  }
  
  if (aniChoice == 2 ) {
    whiteOut();
  }
  
  if (aniChoice == 3 ) {
    matrix.clear();
    matrix2.clear();
    matrix.writeDisplay();  
    matrix2.writeDisplay();  
    sweep();
  } 
  
  if (aniChoice == 4 ) {
    matrixy();
  }   
   
  if (aniChoice == 5 ) {
    matrix.clear();
    matrix2.clear();
    matrix.writeDisplay();  
    matrix2.writeDisplay();         
    delay(100);
    drawDisplay(); 
    delay(100);
    matrix.clear();
    matrix2.clear();
    matrix.writeDisplay();  
    matrix2.writeDisplay();         
    delay(100);
    drawDisplay();  
    delay(100);
    matrix.clear();
    matrix2.clear();
    matrix.writeDisplay();  
    matrix2.writeDisplay();         
    delay(100);
    drawDisplay();    
  }
 
}

void doAnimation () {
   bool isRandom = false;
  
  if( aniChoice > 5) {
     aniChoice = 0; 
  }
  
  if(aniChoice == 5) {
    isRandom = true;
    int randAni[4] = {1,2,3,4};
    bubbleUnsort(randAni,4);
    aniChoice = randAni[0];  
  }
  
  if (aniChoice == 0 ) {
    drawDisplay();
  }
  
  if (aniChoice == 1 ) {
    fadeOut();
  }
  
  if (aniChoice == 2 ) {
    whiteOut();
  }
  
  if (aniChoice == 3 ) {
    sweep();
  } 
  
  if (aniChoice == 4 ) {
    matrixy();
  }   
 
  if( isRandom == true) {
    aniChoice = 5;
  }    
}

//Math!
void bubbleUnsort(int *list, int elem)
{
 for (int a=elem-1; a>0; a--)
 {
   //int r = random(a+1);
   int r = rand_range(a+1);
   if (r != a)
   {
     int temp = list[a];
     list[a] = list[r];
     list[r] = temp;
   }
 }
}

// generate a value between 0 <= x < n, thus there are n possible outputs
int rand_range(int n)
{
   int r, ul;
   ul = RAND_MAX - RAND_MAX % n;
   while ((r = random(RAND_MAX+1)) >= ul);
   return r % n;
}



void software_Reset() // Restarts program from beginning but does not reset the peripherals and registers
{
  asm volatile ("  jmp 0");  
} 

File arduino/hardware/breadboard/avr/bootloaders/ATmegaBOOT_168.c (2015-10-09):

/**********************************************************/
/* Serial Bootloader for Atmel megaAVR Controllers        */
/*                                                        */
/* tested with ATmega8, ATmega128 and ATmega168           */
/* should work with other mega's, see code for details    */
/*                                                        */
/* ATmegaBOOT.c                                           */
/*                                                        */
/*                                                        */
/* 20090308: integrated Mega changes into main bootloader */
/*           source by D. Mellis                          */
/* 20080930: hacked for Arduino Mega (with the 1280       */
/*           processor, backwards compatible)             */
/*           by D. Cuartielles                            */
/* 20070626: hacked for Arduino Diecimila (which auto-    */
/*           resets when a USB connection is made to it)  */
/*           by D. Mellis                                 */
/* 20060802: hacked for Arduino by D. Cuartielles         */
/*           based on a previous hack by D. Mellis        */
/*           and D. Cuartielles                           */
/*                                                        */
/* Monitor and debug functions were added to the original */
/* code by Dr. Erik Lins, chip45.com. (See below)         */
/*                                                        */
/* Thanks to Karl Pitrich for fixing a bootloader pin     */
/* problem and more informative LED blinking!             */
/*                                                        */
/* For the latest version see:                            */
/* http://www.chip45.com/                                 */
/*                                                        */
/* ------------------------------------------------------ */
/*                                                        */
/* based on stk500boot.c                                  */
/* Copyright (c) 2003, Jason P. Kyle                      */
/* All rights reserved.                                   */
/* see avr1.org for original file and information         */
/*                                                        */
/* This program is free software; you can redistribute it */
/* and/or modify it under the terms of the GNU General    */
/* Public License as published by the Free Software       */
/* Foundation; either version 2 of the License, or        */
/* (at your option) any later version.                    */
/*                                                        */
/* This program is distributed in the hope that it will   */
/* be useful, but WITHOUT ANY WARRANTY; without even the  */
/* implied warranty of MERCHANTABILITY or FITNESS FOR A   */
/* PARTICULAR PURPOSE.  See the GNU General Public        */
/* License for more details.                              */
/*                                                        */
/* You should have received a copy of the GNU General     */
/* Public License along with this program; if not, write  */
/* to the Free Software Foundation, Inc.,                 */
/* 59 Temple Place, Suite 330, Boston, MA  02111-1307 USA */
/*                                                        */
/* Licence can be viewed at                               */
/* http://www.fsf.org/licenses/gpl.txt                    */
/*                                                        */
/* Target = Atmel AVR m128,m64,m32,m16,m8,m162,m163,m169, */
/* m8515,m8535. ATmega161 has a very small boot block so  */
/* isn't supported.                                       */
/*                                                        */
/* Tested with m168                                       */
/**********************************************************/

/* $Id$ */


/* some includes */
#include <inttypes.h>
#include <avr/io.h>
#include <avr/pgmspace.h>
#include <avr/interrupt.h>
#include <avr/wdt.h>
#include <util/delay.h>

/* the current avr-libc eeprom functions do not support the ATmega168 */
/* own eeprom write/read functions are used instead */
#if !defined(__AVR_ATmega168__) || !defined(__AVR_ATmega328P__)
#include <avr/eeprom.h>
#endif

/* Use the F_CPU defined in Makefile */

/* 20060803: hacked by DojoCorp */
/* 20070626: hacked by David A. Mellis to decrease waiting time for auto-reset */
/* set the waiting time for the bootloader */
/* get this from the Makefile instead */
/* #define MAX_TIME_COUNT (F_CPU>>4) */

/* 20070707: hacked by David A. Mellis - after this many errors give up and launch application */
#define MAX_ERROR_COUNT 5

/* set the UART baud rate */
/* 20060803: hacked by DojoCorp */
//#define BAUD_RATE   115200
#ifndef BAUD_RATE
#define BAUD_RATE   19200
#endif


/* SW_MAJOR and MINOR needs to be updated from time to time to avoid warning message from AVR Studio */
/* never allow AVR Studio to do an update !!!! */
#define HW_VER	 0x02
#define SW_MAJOR 0x01
#define SW_MINOR 0x10


/* Adjust to suit whatever pin your hardware uses to enter the bootloader */
/* ATmega128 has two UARTS so two pins are used to enter bootloader and select UART */
/* ATmega1280 has four UARTS, but for Arduino Mega, we will only use RXD0 to get code */
/* BL0... means UART0, BL1... means UART1 */
#ifdef __AVR_ATmega128__
#define BL_DDR  DDRF
#define BL_PORT PORTF
#define BL_PIN  PINF
#define BL0     PINF7
#define BL1     PINF6
#elif defined __AVR_ATmega1280__ 
/* we just don't do anything for the MEGA and enter bootloader on reset anyway*/
#else
/* other ATmegas have only one UART, so only one pin is defined to enter bootloader */
#define BL_DDR  DDRD
#define BL_PORT PORTD
#define BL_PIN  PIND
#define BL      PIND6
#endif


/* onboard LED is used to indicate, that the bootloader was entered (3x flashing) */
/* if monitor functions are included, LED goes on after monitor was entered */
#if defined __AVR_ATmega128__ || defined __AVR_ATmega1280__
/* Onboard LED is connected to pin PB7 (e.g. Crumb128, PROBOmega128, Savvy128, Arduino Mega) */
#define LED_DDR  DDRB
#define LED_PORT PORTB
#define LED_PIN  PINB
#define LED      PINB7
#else
/* Onboard LED is connected to pin PB5 in Arduino NG, Diecimila, and Duomilanuove */ 
/* other boards like e.g. Crumb8, Crumb168 are using PB2 */
#define LED_DDR  DDRB
#define LED_PORT PORTB
#define LED_PIN  PINB
#define LED      PINB5
#endif


/* monitor functions will only be compiled when using ATmega128, due to bootblock size constraints */
#if defined(__AVR_ATmega128__) || defined(__AVR_ATmega1280__)
#define MONITOR 1
#endif


/* define various device id's */
/* manufacturer byte is always the same */
#define SIG1	0x1E	// Yep, Atmel is the only manufacturer of AVR micros.  Single source :(

#if defined __AVR_ATmega1280__
#define SIG2	0x97
#define SIG3	0x03
#define PAGE_SIZE	0x80U	//128 words

#elif defined __AVR_ATmega1281__
#define SIG2	0x97
#define SIG3	0x04
#define PAGE_SIZE	0x80U	//128 words
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

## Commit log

2015-10-09 KiCad Design Files
    Initial add of KiCad Design files
    [AllinOneLarge_SMD-B_Cu.gbl, AllinOneLarge_SMD-B_Mask.gbs, AllinOneLarge_SMD-B_SilkS.gbo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]
2015-10-09 Inkscape files
    These are the design files for the laser etched faceplates and were
    designed in Inkscape. Quarter time denotes "Quarter til ten in the
    morning", "Half past nine at night". Non-quarter time would be "nine
    forty five in the morning", "nine thirty at night".
2015-10-09 Work In Progress Kickstarter Redesign
    Adding support for plug in modules and through hole components. Adding
    prototyping area.
    [LargeKickstarter.dsn, LargeKickstarter.kicad_pcb, LargeKickstarter.sch]
2015-10-09 Arduino files
    Clock16x16RTC_animations is for non-Quarter time face.
    Clock16x16RTC_q_animations is for quarter time face. matrix_test is
    just all on (good for testing connections after soldering.) Included
    Adafruit libraries and hardware profile for bare Atmega328.
2015-10-09 Deleted old version.
    [AllinOneLarge_SMD-B_Cu.gbl, AllinOneLarge_SMD-B_Mask.gbs, AllinOneLarge_SMD-B_SilkS.gbo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]
2015-10-15 Full Redesign
    Doubled LED count. Added footprints for modules. Still need DS3231
    module added.
    [LargeKickstarter.kicad_pcb, LargeKickstarter.sch]
2015-10-15 Added DS3231 module footprints
    [LargeKickstarter.kicad_pcb, LargeKickstarter.sch]
2015-10-16 Started on silkscreens
    [LargeKickstarter-B_Cu.gbl, LargeKickstarter-B_Mask.gbs, LargeKickstarter-B_SilkS.gbo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]
2015-10-23 Prelim Gerbers Added
    [LargeKickstarter-B_Cu.gbl, LargeKickstarter-B_Mask.gbs, LargeKickstarter-B_SilkS.gbo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]
2015-11-06 Further tweaks
    Added PTH components for power section and buttons. Fixed some
    disconnects.
    [LargeKickstarter.kicad_pcb, _saved_LargeKickstarter.sch]
2015-11-07 SVGs
    Generated SVG plot for silkscreen creation
2015-11-07 PCB Tweaks
    [LargeKickstarter.kicad_pcb]
2015-11-07 Schematic Tweaks
    [LargeKickstarter.sch, _saved_LargeKickstarter.sch]
2015-11-09 Finished up new silk screens
    [LargeKickstarter-B_Cu.gbl, LargeKickstarter-B_Mask.gbs, LargeKickstarter-B_SilkS.gbo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]
2015-11-09 Continuity Check
    [LargeKickstarter-B_Cu.gbl, LargeKickstarter-B_Mask.gbs, LargeKickstarter-B_SilkS.gbo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]
2015-11-11 Minor tweaks and gerber generation.
    [LargeKickstarter.sch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]
2015-11-24 Final changes and publication
    [LargeKickstarter-B_Cu.gbl, LargeKickstarter-B_Mask.gbs, LargeKickstarter-B_SilkS.gbo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]
